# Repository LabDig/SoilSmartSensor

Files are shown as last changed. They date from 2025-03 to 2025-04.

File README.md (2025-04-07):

# SoilSmartSensor

Esse repositório reune a documentação para construção da plataforma multisensor SoilSmartSensor. 

O Soil Smart Sensor é uma plataforma multisensor e portátil em desenvolvimento do Depto de Engenharia Agrícola da Universidade Federal de Viçosa. O Soil Smart Sensor permite medir a condutividade eletríca aparente , o teor de água e a umidade do solo. A operação do multisensor é realizado por aplicativo executado em dispositivo móvel Android.

Projeto Financiado pelo Conselho Nacional de Desenvovlimento Científico e Tecnológico (CNPq). Tìtulo : Desenvolvimento de um sistema inteligente para caracterização da variabilidade espacial do solo em agricultura de precisão . Processo 404374/2021-2 

Equipe de Desenvolvimento e Validação

Andre Luiz de Freitas Coelho

Daniel Marçal de Queiroz

Emanoel Di Tarso dos Santos Sousa

Eduardo Leonel Bottega

Marcelo Marques da Costa

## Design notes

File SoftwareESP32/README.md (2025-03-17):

# SoilSmartSensor

# SoftwareESP32

Esse diretorio contém ao software desenvolvido para a placa de aquisição de dados do Soil Smart Sensor. 

A placa de aquisição do Soil Smart Sensor utiliza como base a placa de desenvolvimento ESP32 S3.

Documentação da placa em https://docs.espressif.com/projects/esp-dev-kits/en/latest/esp32s3/esp32-s3-devkitc-1/index.html

O software foi desenvolvido no Arduino IDE 2.3.2 com firmware para a familia de placas ESP32 versão 3.0.5

Detalhamento dos arquivos e diretórios

/SmartSensor_ESP32  --> contém os arquivos do software desenvolvido para ESP32 S3
 SmartSensor_ESP32.ino  --> arquivo principal com o software
 functions.ino            --> arquivo auxiliar com funções utilizadas.

/NimBLE-Arduino    --> contém a biblioteca para uso do Bluetooth Low Energy

/Sparkfun_ADS1015_Arduino_Library --> contém a biblioteca para uso do módulo ADC ADS1015

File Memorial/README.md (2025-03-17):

# SoilSmartSensor

# Memorial

Esse diretorio contém o Memorial Descrito e Manual de Operação do Soil Smart Sensor. 

Detalhamento dos arquivos e diretórios

Memorial_Manual.pdf --> Memorial Descritivo e Manual de Operação do Soil Smart Sensor

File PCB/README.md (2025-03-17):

# SoilSmartSensor

# PCB

Esse repositório reune a documentação para construção da placa de circuito impresso para o Soil Smart Sensor. 

A placa é desenvolvida com base na ESP32 S3

O projeto do circuito foi desenvolvido utilizando o Fritzing (https://fritzing.org/)

Detalhamento dos arquivos e diretórios

PCB.fpz --> arquivo Fritzing

PCB_Esquematico.pdf --> ciruito eletronico da placa do Soil Smart Sensor

PCB_trilhas.pdf --> trilhas da placa do Soil Smart Sensor

ListaMateriais_PCB.csv --> Lista de materiais para fabricação da PCB e Unidade Eletronica de Controle

/Gerber --> diretorio com os arquivos Gerber para confecção da PCB

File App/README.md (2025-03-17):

# SoilSmartSensor

# App

Esse diretorio contém os arquivos relacionados ao aplicativo Android para operação do Soil Smart Sensor. 

O aplicativo foi desenvolvido utilizando a plataforma online MIT App Inventor (https://appinventor.mit.edu/)

Detalhamento dos arquivos e diretórios

/PrintScreen --> contém capturas de tela do aplicativo

BLE-with-extensios-api.apx --> Extensão para usar os recursos do Bluetooth Low Energy (BLE)

SmartSensor3.aia --> arquivo aia gerado pelo AppInventor. Você pode importar e editar o aplicativo a partir desse arquivo

SmartSensor3.apk --> arquivo APK para instalação do aplicativo em dispositivo Android

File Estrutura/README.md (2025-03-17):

# SoilSmartSensor

# Estrutura

Esse diretorio contém os arquivos relacionados à estrutura (chassi) do Soil Smart Sensor. 

O aplicativo foi desenvolvido utilizando a plataforma online MIT App Inventor (https://appinventor.mit.edu/)

Detalhamento dos arquivos e diretórios

Estrutura.step --> modelagem 3D da estrutura

ListaMateriaisEstrutura.csv --> Lista de materiais e respectivas quantidades para construção da estrutura

DesenhoTecnico.pdf --> Desenho técnico para construção da estrutura

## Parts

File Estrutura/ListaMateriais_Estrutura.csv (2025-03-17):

Qtde | unididade | Descrição
1 | m | TUBO QUADRADO DE ALUMÍNIO 1. 1/2" (38,10 MM) X 1/16" (1,58 MM)
0.25 | m | TUBO REDONDO DE ALUMÍNIO DE 7/8" (22,22 MM) X 1/16" (1,58 MM)
2 | m | PERFIL RETANGULAR AÇO SAE 1020 1.1/2" (38.1 MM) X 3/16" (4.76 MM)
1 | m | BARRA NYLON 6.0 QUADRADO 40 X 40 MM
1 | m | BARRA CIRCULAR INOX AISI 304 1/4" (6.35 MM)
10 | unid. | PARAFUSO SEXTAVADO 1/4" X 2"
10 | unid. | PORCA SEXTAVADA 1/4"
10 | unid. | ARRUELA LISA 1/4"

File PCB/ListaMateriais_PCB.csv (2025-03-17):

Qtde | Unidade | Descrição
1 | unid. | Carregador Portátil PowerBank 5V 10.000 mAh
1 | unid. | PLACA DE DESENVOLVIMENTO ESP32 S3 - ESP32 S3 DEV KIT
6 | unid. | BATERIA 18650 3.7V 3800mAh
2 | unid. | SUPORTE 3 BATERIA 18650
1 | unid. | MÓDULO RELE 5V 2 CANAIS COM OPTOACOPLADOR
2 | unid. | BARRA PINOS FEMEA 1X40 2.54 MM 180 GRAUS
1 | unid. | CONVERSOR ANALOGICO DIGITAL I2C - 10 bits - ADS1015
1 | unid. | MÓDULO MICRO SD SPI 5 V
1 | unid. | BMS 6S 15A 24V
1 | unid. | FONTE 24 V 2 A PLUG P4
1 | unid. | 1 CONECTOR P4
1 | unid. | 1 CABO USB-C
1 | unid. | SENSOR TEMPERATURA PT100 3 FIOS, CABO 2 METROS, SONDA D= 5 MM X L = 100 MM
1 | unid. | CAIXA ABS 200X 100X100 MM
1 | unid. | CHAVE GANGORRA KCD1-202 6 TERMINAIS
1 | unid. | CONECTOR MIKE 6 VIAS
1 | unid. | VOLTIMETRO INFICADOR CARGA BATERIA 18650 6S
1.5 | m | Cabo Flexível 22 AWG (0,30mm) Azul
1.5 | m | Cabo Flexível 22 AWG (0,30mm) Vermelho
1.5 | m | Cabo Flexível 22 AWG (0,30mm) Preto
1.5 | m | Cabo Flexível 22 AWG (0,30mm) Verde
1.5 | m | Cabo Flexível 22 AWG (0,30mm) Amarelo
3 | unid. | Resistor 1.5 kohm 1/4 W
7 | unid. | Resistor 100 kohm 1/4 W
1 | unid. | Resistor 10 kohm 1/4 W
2 | unid. | Resistor 120 ohm 1/4 W
1 | unid. | Resistor 180 ohm 1/4 W
4 | unid. | Resistor 1 kohm 1/4 W
12 | unid. | Resistor 22 kohm 1/4 W
1 | unid. | Resistor 250 ohm 1/4 W
1 | unid. | Resistor 33 kohm 1/4 W
2 | unid. | Resistor 4.7 kohm 1/4 W
1 | unid. | Resistor 5.6 kohm 1/4 W
1 | unid. | Resistor 510 ohm 1/4 W
2 | unid. | Resistor 6.8 kohm 1/4 W
3 | unid. | Resistor 9.1 kohm 1/4 W
2 | unid. | Capacitor Cerâmico 10 nF
1 | unid. | Capacitor Cerâmico 4.7 nF
5 | unid. | Capacitor Eletrolítico 1 uF 16 V
1 | unid. | Amp Op LM741
1 | unid. | Amp Op LM342N
4 | unid. | Amp Op MCP6002
3 | unid. | Amp Op TL072
1 | unid. | Diodo 1N4001
4 | unid. | Conector KRE 2 Vias
1 | unid. | Conector KRE 3 Vias
1 | unid. | Trimport 10 k
1 | unid. | Conversor Step-Down Mini ajustável 5560
6 | unid. | Soquete DIP 8 pinos
1 | unid. | Soquete DIP 14 pinos

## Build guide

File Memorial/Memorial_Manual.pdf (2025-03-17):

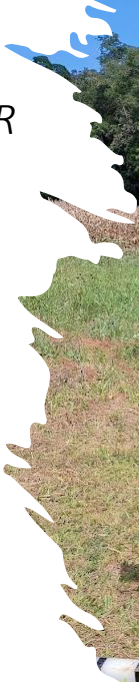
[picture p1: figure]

# PLATAFORMA MULTISENSOR CEA, UMIDADE E TEMPERATURA DO SOLO

# SMART SOIL SENSOR

# MANUAL E MEMORIAL TÉCNICO

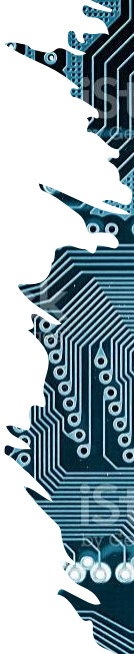
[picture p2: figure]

# PARTE 1 : COMPONENTES

E

# FUNCIONAMENTO

# Plataforma Multisensor

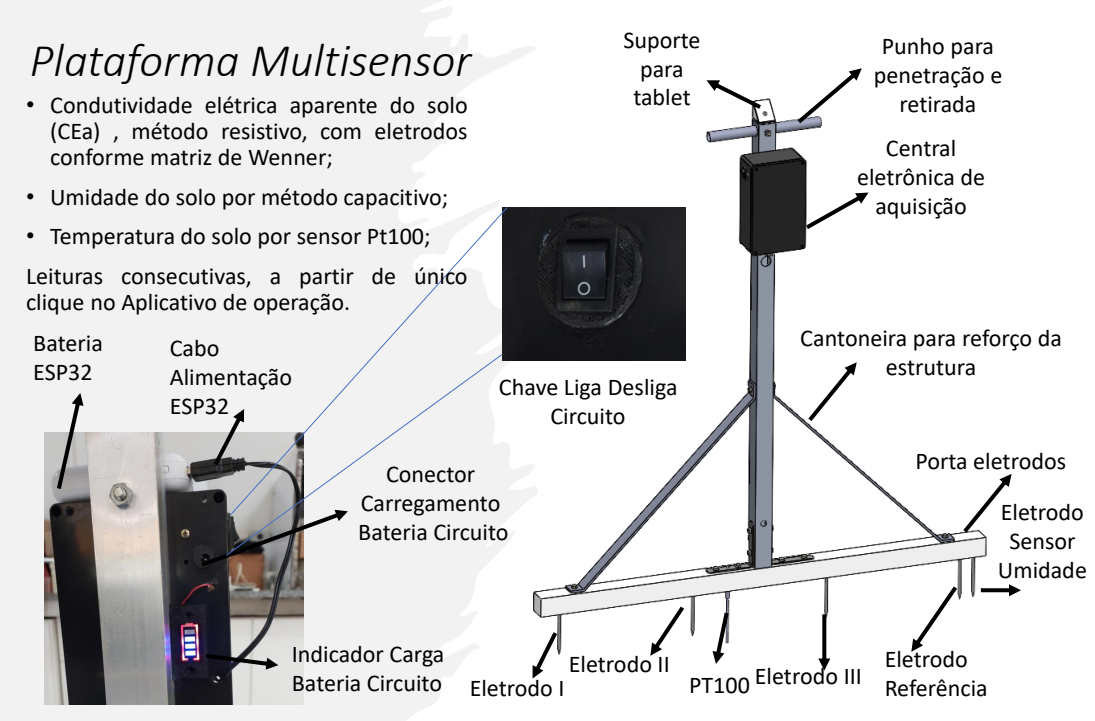
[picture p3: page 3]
Punho para penetração e retirada; Suporte para tablet; Central eletrônica de aquisição; Porta eletrodos; Eletrodo I; Eletrodo Referência; Eletrodo Sensor Umidade; Indicador Carga Bateria Circuito; Conector Carregamento Bateria Circuito; Eletrodo II; Eletrodo III; Cabo Alimentação ESP32; estrutura

• Condutividade elétrica aparente do solo
(CEa) , método resistivo, com eletrodos
conforme matriz de Wenner;
• Umidade do solo por método capacitivo;
• Temperatura do solo por sensor Pt100;
Leituras consecutivas, a partir de único
clique no Aplicativo de operação.
Bateria
ESP32

Cantoneira para reforço da

Chave Liga Desliga
Circuito

# Sensor CEA

- a = 0.3 m;
- h = 9 – 10 cm;

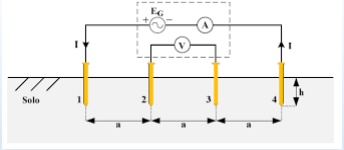
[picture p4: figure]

- EG = Sinal emitido ➔ bipolar , com amplitude – 9 a 9 V, frequência ajustável pelo usuário (3 a 100 Hz) ;
- I = Corrente demandada pelo solo medida a partir da passagem do sinal por resistor com resistência 180 ohm (resistor shunt). Medição da queda de tensão no resistor e cálculo da corrente;
- V = Diferença de potencial nos eletrodos 2 e 3, devido ao sinal elétrico conduzido pelo solo;
- Emissão de sinal ocorre apenas durante leitura da CEa;
- Leitura de 40 pontos dos sinais com taxa de amostragem 8x frequência sinal:
- Queda de tensão no R180 ➔ cálculo CEa e algoritmo de contato;
- Diferença de tensão E2 – Referência ➔ cálculo CEa e algoritmo de contato;
- Diferença de tensão E3 – Referência ➔ cálculo CEa e algoritmo de contato ;
- Cálculo de sinal referente à diferença de potencial entre eletrodo 2 e 3 ➔ cálculo CEa e algoritmo de contato ;
- Cálculo do absoluto dos valores de tensão (queda de tensão R180) e diferença de potencial dos eletrodos intermediários) ➔ cálculo da tensão média do absoluto ➔ cálculo de CEa;

CEa (

mS
m

) =

i (mA)
2 ∙ π ∙ a m ∙ V (V)

!!!!Absoluto : transforma parte negativa do sinal bipolar em positivo por função matemática abs().

# Sensor Umidade Solo

Geração de sinal
contínuo (3V?)

Eletrodo Sensor Umidade

Filtro Resistivo-Capacitivo Condicionamento do sinal (divisor de tensão e filtro)

- Princípio capacitivo : solo atua como capacitor em um filtro RC;
- Solo Seco ➔ Menor Capacitância ➔ Maior tensão SIG_m;
- Solo Úmido ➔ Maior Capacitância ➔ Menor tensão SIG_m;
- Calibração para obter a umidade (gravimétrica ou volumétrica) a partir da tensão SIG_m.

Eletrodo Referência

# Sensor Temperatura Solo

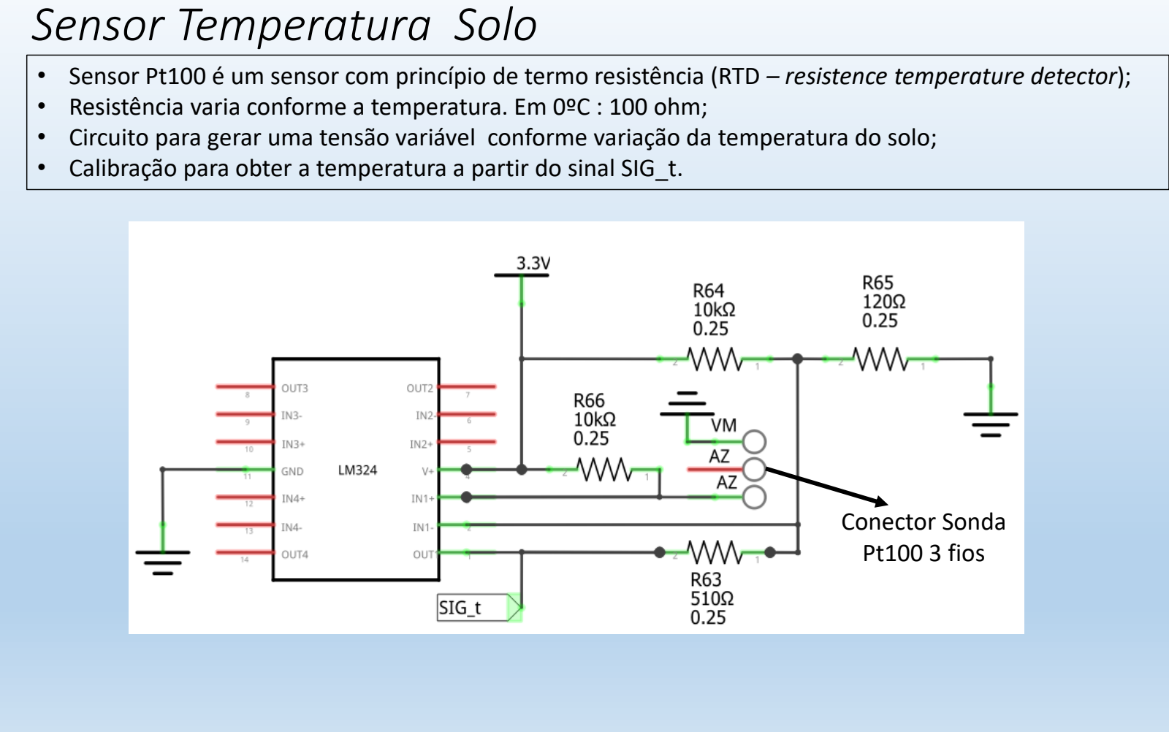
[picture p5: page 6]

- Sensor Pt100 é um sensor com princípio de termo resistência (RTD – resistence temperature detector);
- Resistência varia conforme a temperatura. Em 0ºC : 100 ohm;
- Circuito para gerar uma tensão variável conforme variação da temperatura do solo;
- Calibração para obter a temperatura a partir do sinal SIG_t.

Conector Sonda
Pt100 3 fios

# Central eletrônica de aquisição

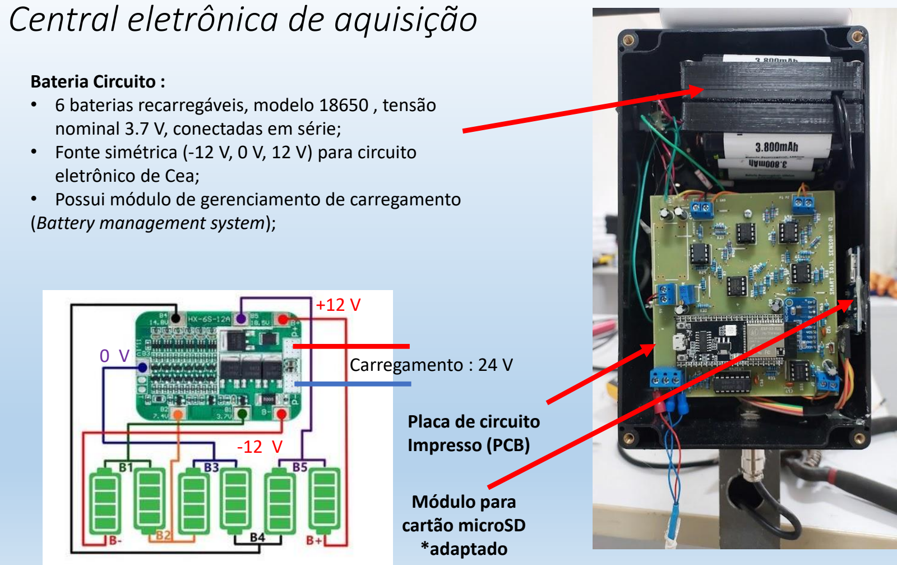
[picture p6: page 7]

Bateria Circuito :
- 6 baterias recarregáveis, modelo 18650 , tensão nominal 3.7 V, conectadas em série;
- Fonte simétrica (-12 V, 0 V, 12 V) para circuito eletrônico de Cea;
- Possui módulo de gerenciamento de carregamento (Battery management system);

Carregamento : 24 V

+12 V

0 V

-12 V

Placa de circuito
Impresso (PCB)

Módulo para
cartão microSD
*adaptado

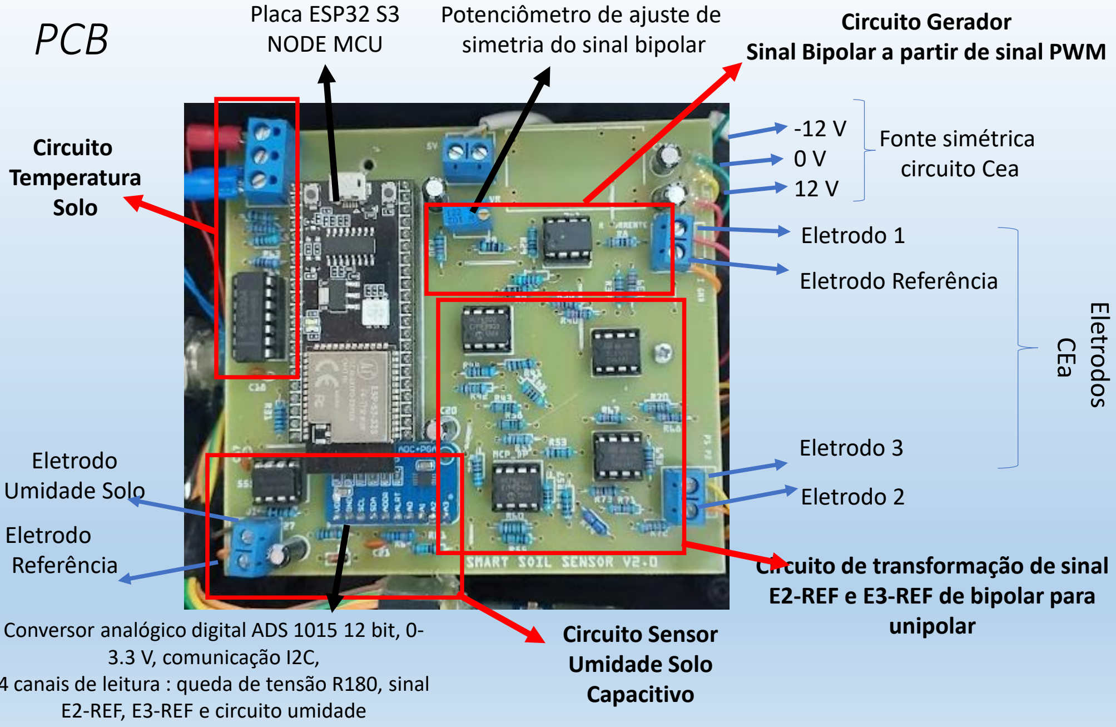
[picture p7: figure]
Placa ESP32 S3 NODE MCU; Eletrodo 1; Eletrodo Referência; Eletrodo 3; Eletrodo 2; Potenciômetro de ajuste de simetria do sinal bipolar; Fonte simétrica circuito Cea; Eletrodos; CEa; Eletrodo Umidade Solo; 3.3 V, comunicação I2C,; E2-REF, E3-REF e circuito umidade; Circuito Sensor Umidade Solo Capacitivo; Circuito Gerador Sinal Bipolar a partir de sinal PWM; Circuito de transformação de sinal E2-REF e E3-REF de bipolar para unipolar; PCB; Circuito Temperatura Solo

Conversor analógico digital ADS 1015 12 bit, 0-

4 canais de leitura : queda de tensão R180, sinal

# PCB

Placa ESP32 S3

-12 V
0 V
12 V

Eletrodo 1

Eletrodo Referência

Eletrodo 3

Eletrodo 2

Potenciômetro de ajuste de simetria do sinal bipolar

Fonte simétrica
circuito Cea

Eletrodos

CEa

Eletrodo
Referência

Eletrodo
Umidade Solo

Conversor analógico digital ADS 1015 12 bit, 0-3.3 V, comunicação I2C,
4 canais de leitura : queda de tensão R180, sinal E2-REF, E3-REF e circuito umidade

Circuito Sensor
Umidade Solo
Capacitivo

Circuito Gerador
Sinal Bipolar a partir de sinal PWM

Circuito de transformação de sinal E2-REF e E3-REF de bipolar para unipolar

Circuito
Temperatura
Solo

Acionamento
Relés

Alimentação 5V

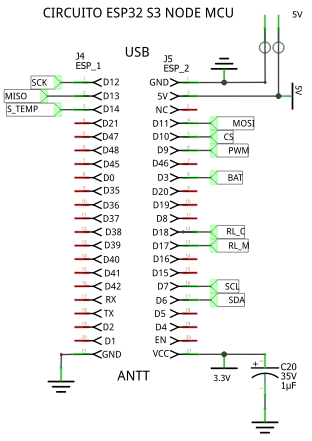
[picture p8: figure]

5V : Entrada de energia para alimentar ESP32-S3

GND : Referência (0V)

3.3V : fornecimento de 3.3V para Circuitos diversos

PWM : sinal PWM para Gerador de Sinal Bipolar

BAT : medição da tensão da bateria do circuito (+12V)

RL_C : acionamento do relé de emissão do sinal para medição da Cea

RL_M : acionamento do relé do sinal para medição da umidade

SCL e SDA : comunicação I2C com ADS1015

S_TEMP : sinal do sensor de temperatura

SCK, MISO, MOSI, CS : comunicação SPI com módulo microSD

# Circuito ESP32-S3 NODE MCU

# Circuito Tensão Baterias 18650 , ADS1015 e Relés

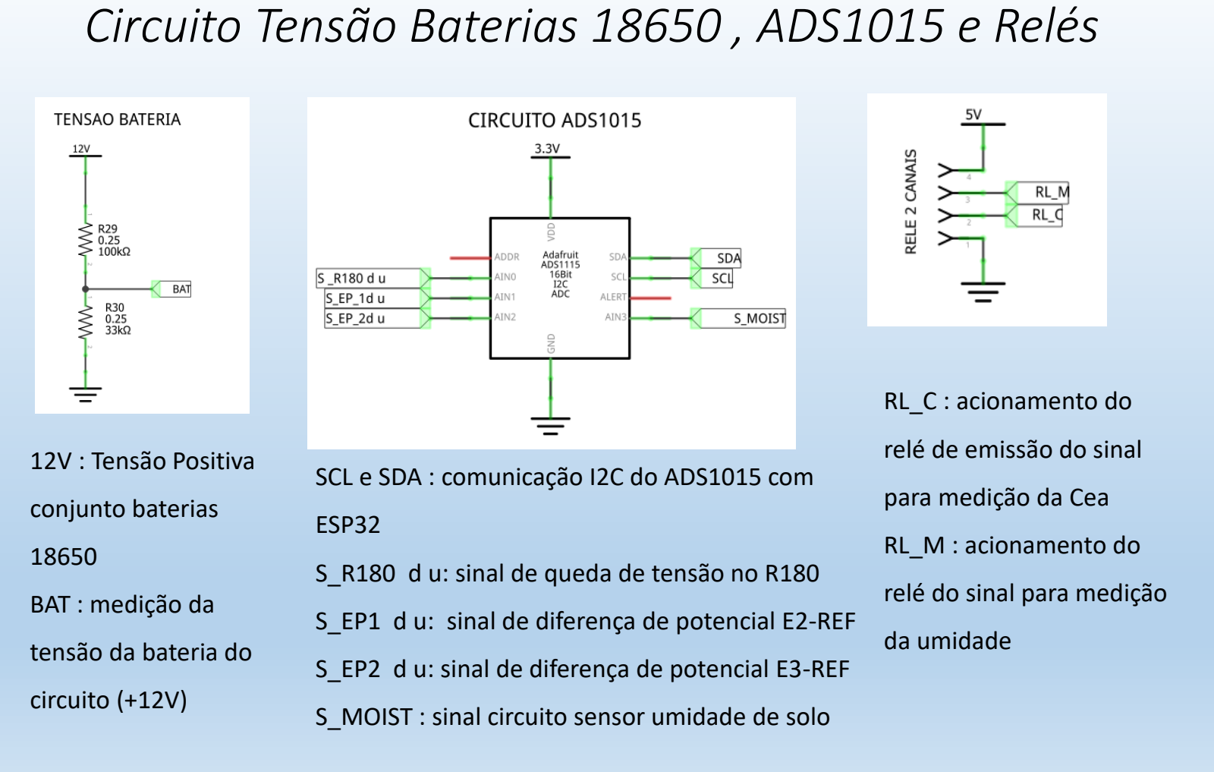
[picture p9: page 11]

12V : Tensão Positiva

conjunto baterias

18650

BAT : medição da

tensão da bateria do

circuito (+12V)

SCL e SDA : comunicação I2C do ADS1015 com

ESP32

S_R180 d u: sinal de queda de tensão no R180

S_EP1 d u: sinal de diferença de potencial E2-REF

S_EP2 d u: sinal de diferença de potencial E3-REF

S_MOIST : sinal circuito sensor umidade de solo

RL_C : acionamento do

relé de emissão do sinal

para medição da Cea

RL_M : acionamento do

relé do sinal para medição

da umidade

5V : Alimentação

GND : Referência (0V)

MOSI : Master Out Slave In

MISO : Master In Slave Out

SCK : Serial Clock

CS : Chipt Select

# Circuito Módulo MicroSD

SPI

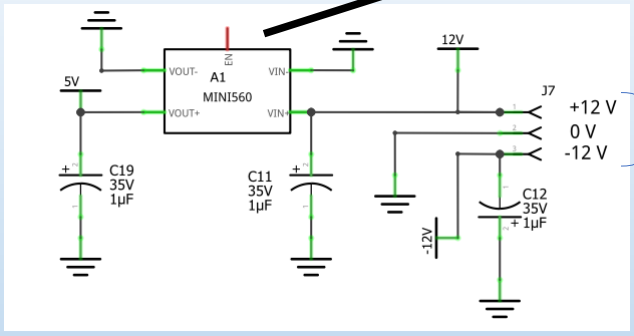
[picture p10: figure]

12V : Tensão Positiva conjunto baterias 18650

-12V : Tensão Negativa conjunto baterias 18650

5 V : Tensão para alimentar ESP32 S3 e Gerador Bipolar

! Não está sendo usado na versão atual do Smart Soil Sensor

# Circuito Regulador de Tensão

Conversor de tensão Mini 560 DC-DC 12 V ➔ 5V

Fonte simétrica
circuito

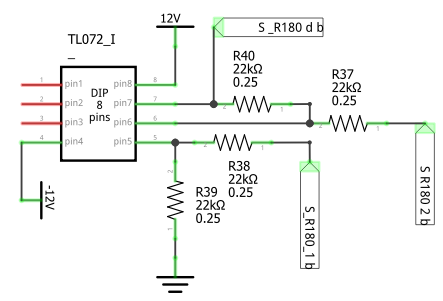
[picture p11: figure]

S_R180 d b : sinal da queda de tensão no R180 (sinal bipolar)

# Circuito Gerador de sinal diferencial para queda de tensão R180

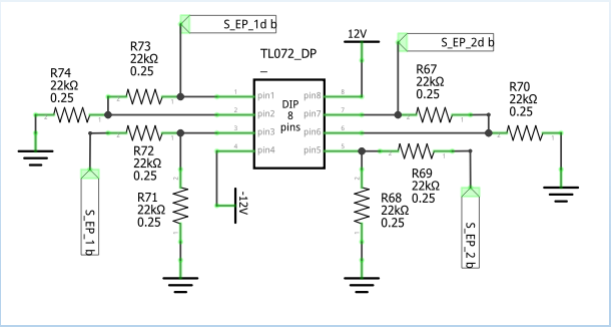
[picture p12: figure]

S_EP_1 d b : sinal potencial eletrodo E2 em relação ao GND (sinal bipolar)

S_EP_2 d b : sinal potencial eletrodo E3 em relação ao GND (sinal bipolar)

# Circuito Gerador de sinal diferencial Eletrodos E2 e E3

# Diagrama Transformador de sinal bipolar (-5 a 5 V ) em sinal unipolar (0 a 3.3V) Queda Tensão R180

S_R180 d b : queda de tensão no R180 bipolar➔ S_R180 d u : queda de tensão no R180 unipolar

# Diagrama Transformador de sinal bipolar (-5 a 5 V ) em sinal unipolar (0 a 3.3V)

Desenvolvido com base no circuito apresentado em Molloy, D. Exploring BeagleBone : Tools and Techniques for Building With Embeeded Linux. Indianapolis : John Willey& Sons, Inc. 20215.

Circuito com base no amplificador operacional MCP6002

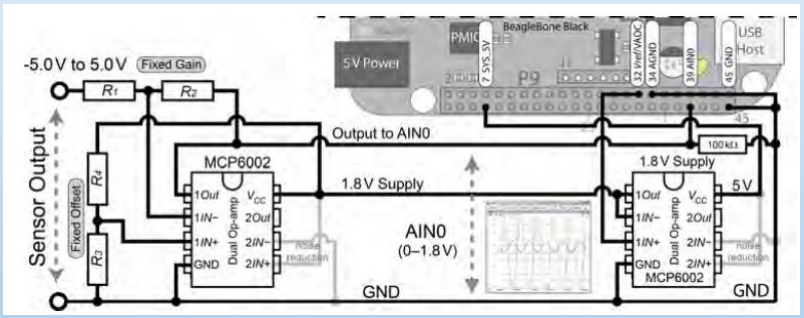
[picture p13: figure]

Equação matemática do circuito

# Circuito Transformador de sinal bipolar (-5 a 5 V ) em sinal unipolar (0 a 3.3V) Eletrodos E2 e E3

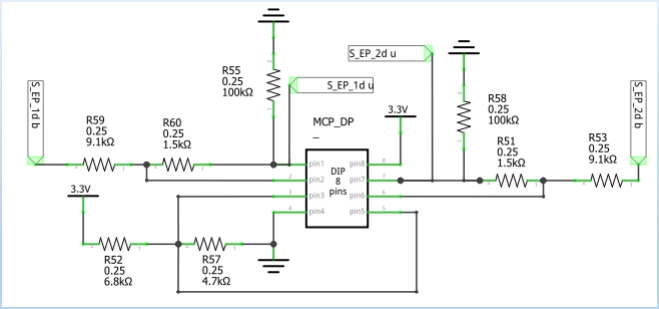
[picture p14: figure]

S_EP1 d b : diferença potencial E2-REP bipolar➔ S_EP1 d u : diferença potencial E2-REP unipolar

S_EP2 d b : diferença potencial E3-REP bipolar➔ S_EP2 d u : diferença potencial E3-REP unipolar

# Circuito sensor de umidade do solo

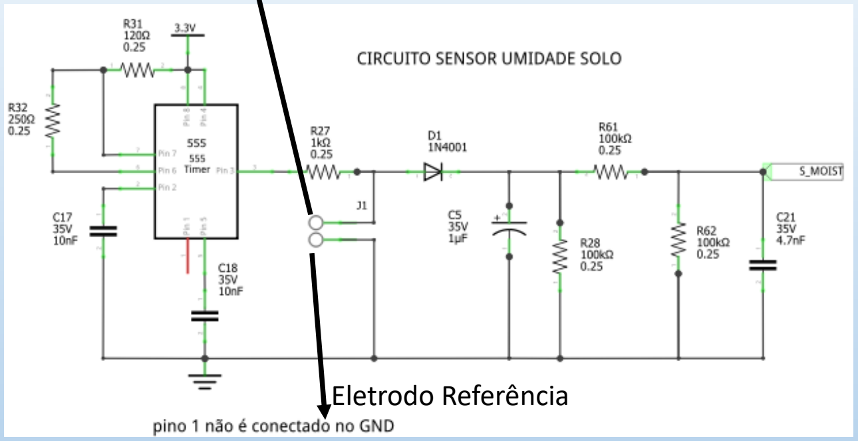
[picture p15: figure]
Eletrodo Referência

Sinal SIG_MOIST está relacionado com a umidade do solo ➔ Leitura no canal 3 do ADS1015

Umidade baixa ➔ maior tensão / umidade alta ➔ menor tensão

Requer calibração experimental para gerar equação matemática para determinar umidade

Eletrodo Sensor Umidade

* Sinal enviado para Eletrodo Sensor Umidade é interrompido por relé , quando o sensor não está medindo umidade do solo

# Circuito sensor de temperatura do solo

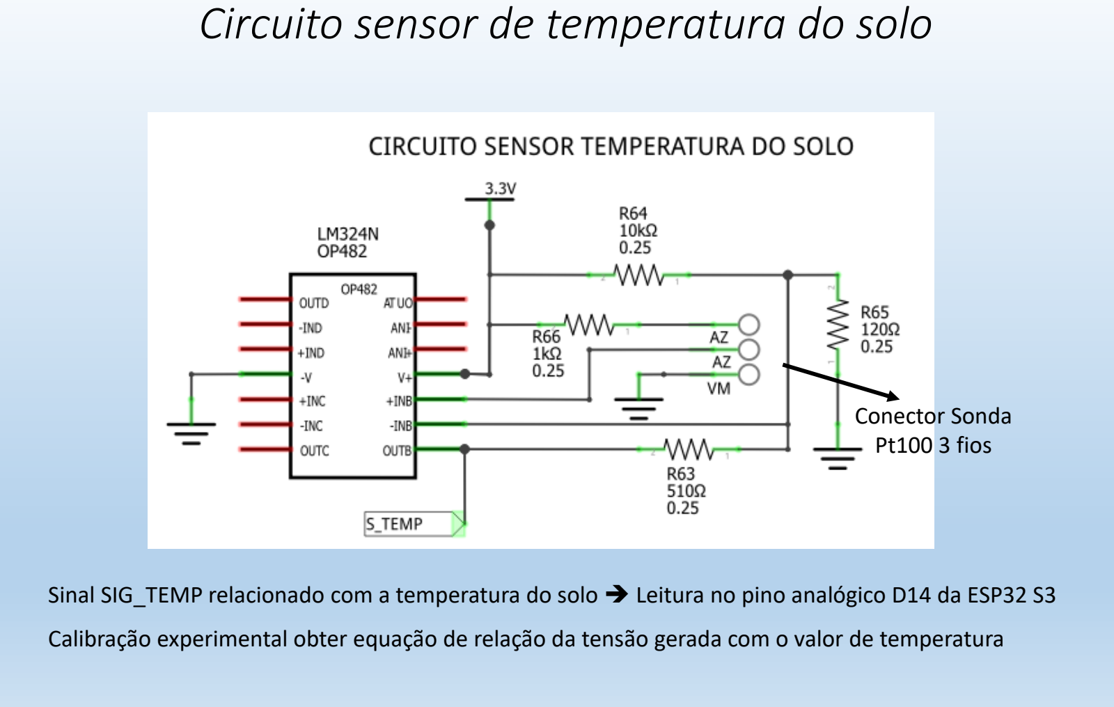
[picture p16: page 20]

Sinal SIG_TEMP relacionado com a temperatura do solo ➔ Leitura no pino analógico D14 da ESP32 S3

Calibração experimental obter equação de relação da tensão gerada com o valor de temperatura

Conector Sonda
Pt100 3 fios

# PARTE 2 : PROGRAMA

DE

# COMPUTADOR

# Fluxograma Programa

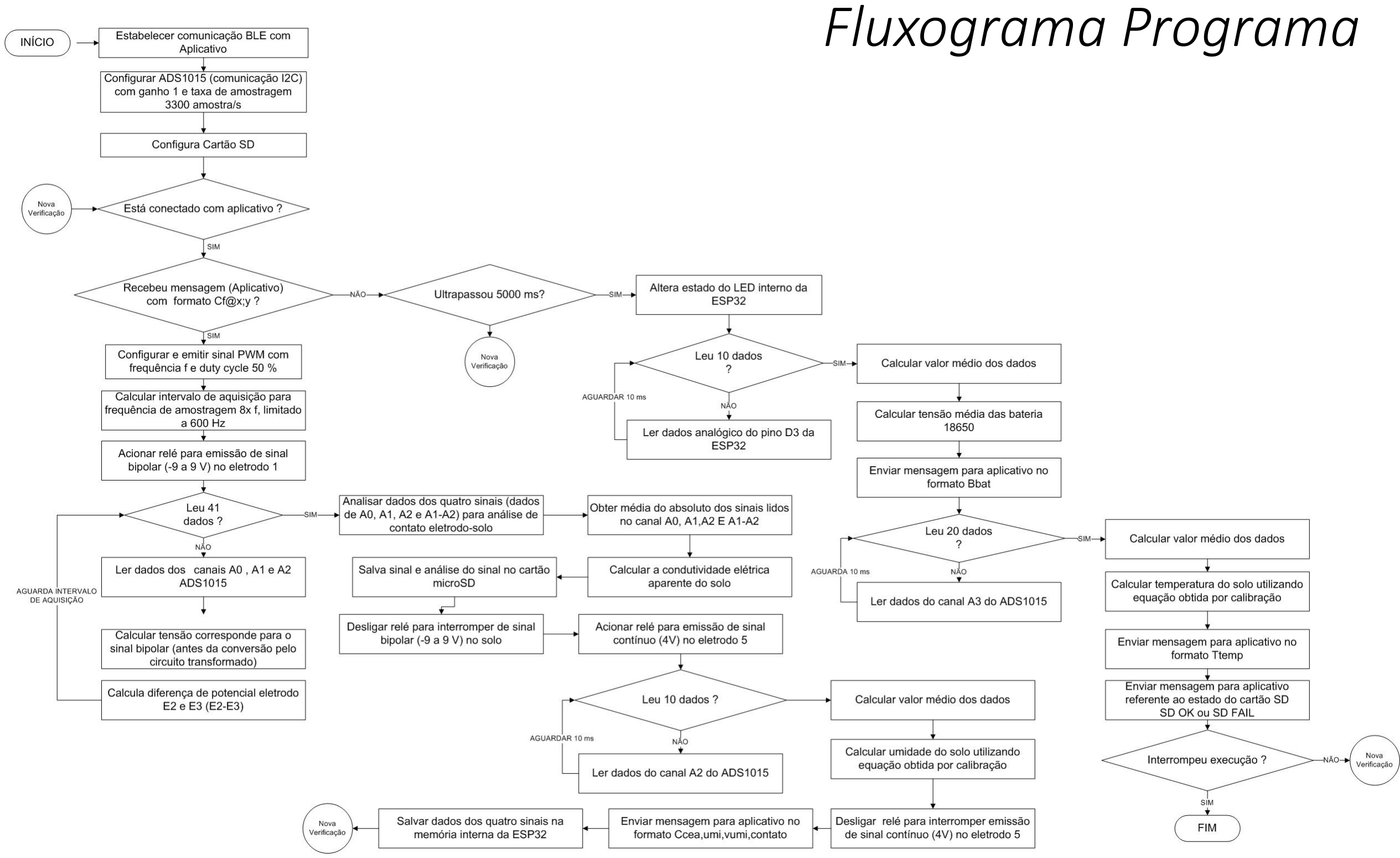
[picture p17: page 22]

# Detalhes do cálculo da CEa

- Para o sinal de queda de tensão no R180 :
- Calcula o valor médio do sinal absoluto ➔ tensões negativas são convertidas em

positivas;

- Calcula a corrente média do sinal;
- Para o sinal de diferença de potência entre eletrodos E2 e E3:
- Calcula o valor médio do sinal absoluto ➔ tensões negativas são convertidas em

positivas;

- Calcula a Cea, usando a equação: CEa (

mS
m

) =

i (mA)
2 ∙ π ∙ a m ∙ V (V)

# Detalhes do algoritmo de contato

- Após a aquisição dos 40 dados dos 4 sinais (R180, E2-REF, E3-REF, E2-E3), eles são analisados.
- Durante a análise, cada um dos 4 sinais é divido em alto (HIGH) e baixa (LOW):
- Após a contagem do número de dados em HIGH e LOW , é calculado a razão entre

número de dados entre LOW e HIGH (rn_lh);

- Após o cálculo da tensão média em HIGH e LOW , É calculado a razão entre a tensão em

HIGH e LOW (rv_lh);

# Detalhes do algoritmo de contato

- Hipóteses adotadas para o desenvolvimento do algoritmo:
- 1 ) O sinal emitido no solo é bipolar e simétrico. Então, o número de pontos na parte HIGH

e LOW de cada um dos quatro sinais precisam ser próximos (razão rn_lh próximo de 1).

- 2 ) O sinal emitido Sinal emitido é bipolar e simétrico. Então, a magnitude da tensão média

em HIGH e LOW dos sinais usados para calcular Cea ser próximos (rv_lh próximo de -1).

- Caso algum critério, em algum sinal, não seja atendido, o algoritmo acusa mal contato eletrodo-

solo (contato=N)

- Caso todos os critérios sejam atendidos, o algoritmo considerado contato perfeito (contato = S)

# Detalhes do algoritmo de contato

Faixa de valores para os critérios, definidos após testes em laboratório e campo :

- A razão rn_lh dos sinais precisa estar em 0.5 e 1.5
- A razão rv_lh dos sinais precisa estar em -0.25 e -1.75 *
- Para os quatro sinais R180 (i), E2-REF(EP1), E3-REF(EP2) e E2-E3 (DP), os valores de nl,nh,rn_lh,vl,vh,rv_lh e média (mean) são salvos no arquivo analise.txt
- Os sinais são salvos no arquivo signal.txt
- O programa Python analisa_sinal.py permite analisar o arquivo signal.txt , gerando gráficos do sinal e arquivo com as métricas relacionadas ao sinal.
- O programa Python analisa_dataset.py permite mesclar o arquivo dataset.txt com o arquivo contendo tais métricas.

# Cenário de contato perfeito (solo)

Sinal diferença tensão
Eletrodo E2-REF Sinal queda

tensão R180

Sinal diferença tensão
Eletrodo E2-E3

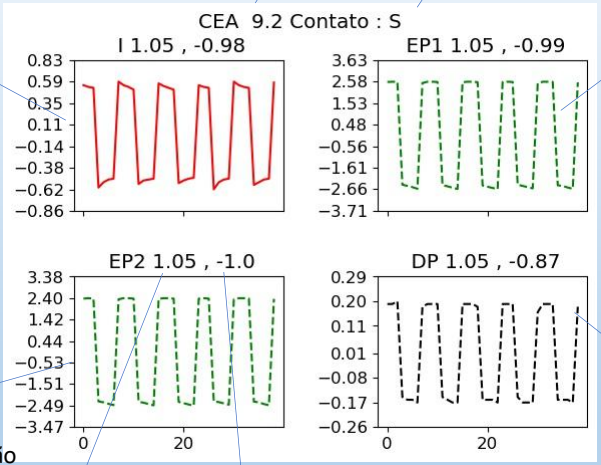
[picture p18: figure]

Sinal diferença tensão
Eletrodo E3-REF

CEA (mS/m)
Contato ?

-0.25 < RV_LH<-1.75 ?

0.5 < RN_LH<1.5 ?

Gráfico gerados em
programa Python
(analise_sinal.py),
usando os dados
gravados no cartão
microSD

# Cenário de contato imperfeito

Sinal diferença tensão
Eletrodo E2-REF Sinal queda

tensão R180

Sinal diferença tensão
Eletrodo E2-E3

Sinal diferença tensão
Eletrodo E3-REF

CEA (mS/m)
Contato ?

-0.25 < RV_LH<-1.75 ?

0.5 < RN_LH<1.5 ?

Gráfico gerados em
programa Python
(analise_sinal.py),
usando os dados
gravados no cartão
microSD

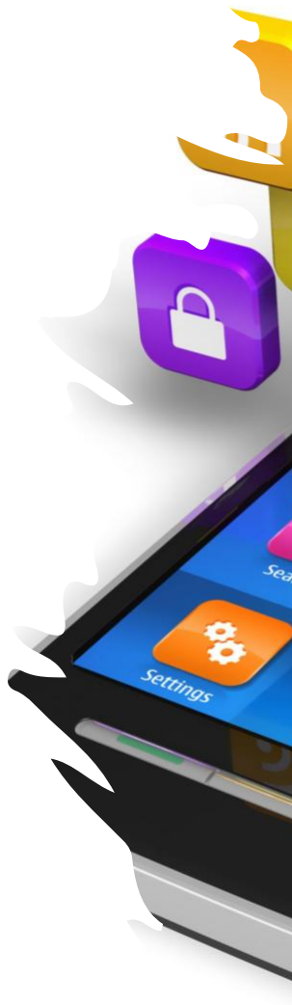
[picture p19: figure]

# PARTE 3 : APLICATIVO

DE

# OPERAÇÃO SMART SENSOR

Descrição dos campos | NOME ARQUIVO : gera , automaticamente, nome do arquivo que será salvo em Documentos/SmartSensor. A pasta e arquivo são gerados, automaticamente , pelo Aplicativo, mesmo que deletados. O formato do arquivo é dataset-yy-mm-dd.txt. A cada dia de coleta, um novo arquivo é gerado.
| ID PROXIMO PONTO : Apresenta o ID do próximo ponto. O ID tem formato X.Y. Onde X é o ID do ponto de fato, e Y é a repetição para aquele ponto. X e Y podem ser editado clicando sobre os respectivos campos. O ID é reiniciado para 1.2 sempre que um novo arquivo é criado. O valor é mantido pelo Aplicativo, mesmo que seja fechado.
| FREQUÊNCIA : Mostra a frequência do sina usando para medição da CEa. O valor pode ser editado clicando sobre o campo. O último valor editado é mantido pelo Aplicativo, mesmo que ele seja fechado.

Descrição dos campos | DATA E HORA : Data e Hora atual obtido do sistema Android. ULTIMO ID : id do último ponto salvo, formato X;Y LAT e LONG : Latitude e Longitude, datum WGS84, em formato de graus e decimal, obtido pelo sensor GNSS do Tablet PRECISÃO : precisão da localização indicada pelo Tablet ALTITUDE : altitude, em relação ao nível do mar, calculada pelo sensor GNSS do tablet CEa SOLO : CEA do solo na última medição. TEMP. SOLO : valor de temperatura do solo na última medição. UMIDADE . SOLO : umidade gravimétrica do solo na última medição, seguido da tensão medida pelo circuito. BATERIA SENSOR : tensão da bateria do sensor. !Interromper a coleta se ficar vermelho
| CONTATO ELETRODO SOLO : S indica contato e N
| indica ausência de contato
SD OK : salvando sinais e analise no cartão microSD SD FAIL : falha no salvamento.

# Descrição dos botões

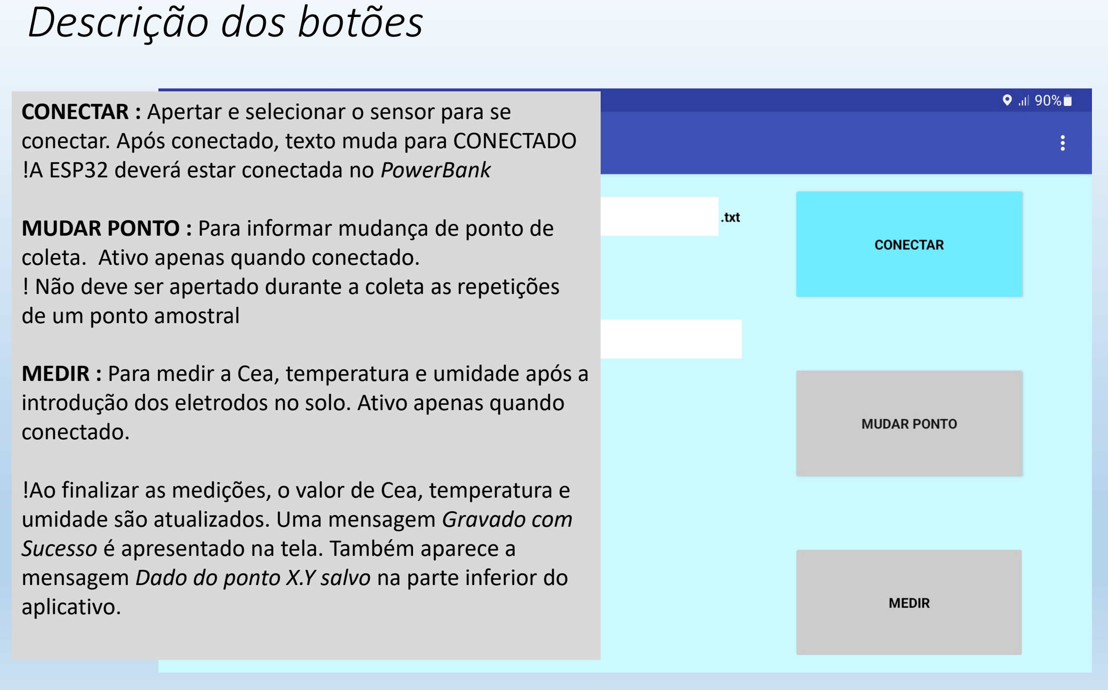
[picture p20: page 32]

CONECTAR : Apertar e selecionar o sensor para se conectar. Após conectado, texto muda para CONECTADO !A ESP32 deverá estar conectada no PowerBank

MUDAR PONTO : Para informar mudança de ponto de coleta. Ativo apenas quando conectado.
! Não deve ser apertado durante a coleta as repetições de um ponto amostral

MEDIR : Para medir a Cea, temperatura e umidade após a introdução dos eletrodos no solo. Ativo apenas quando conectado.

!Ao finalizar as medições, o valor de Cea, temperatura e umidade são atualizados. Uma mensagem Gravado com Sucesso é apresentado na tela. Também aparece a mensagem Dado do ponto X.Y salvo na parte inferior do aplicativo.

# Descrição dos botões

Quando o botão CONECTAR é apertado, surge uma lista de dispositivos próximos para ser selecionado.

Após conectado:
- Botão CONECTAR muda para CONECTADO
- Botão MUDAR PONTO ativo
- Botão MEDIR ativo

Para fechar aplicativo :
- Clicar nos três pontos (1) e em Stop this application (2)

2

1

# Descarregamento dos dados do Tablet

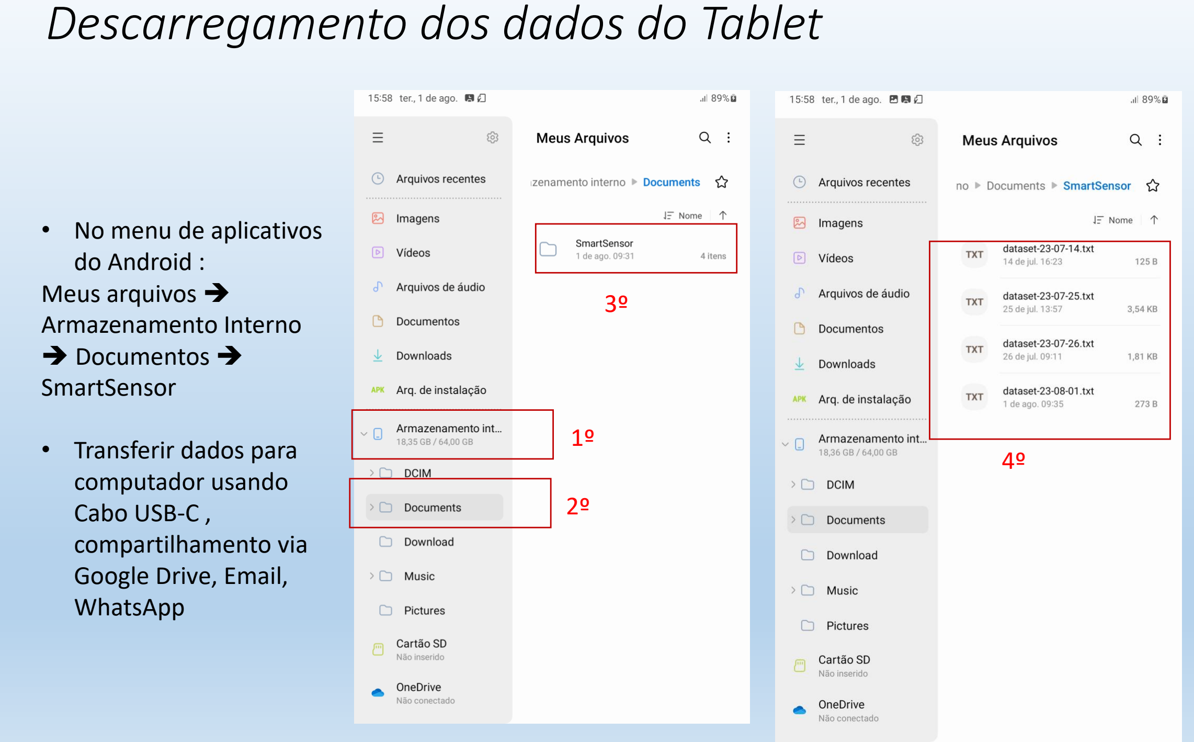
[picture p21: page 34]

- No menu de aplicativos
do Android :
Meus arquivos ➔
Armazenamento Interno
➔ Documentos ➔
SmartSensor
- Transferir dados para
computador usando
Cabo USB-C ,
compartilhamento via
Google Drive, Email,
WhatsApp

1º

2º

3º

4º

# Visualização dos dados do Tablet

Dados em formato csv , utilizando ponto-e-vírgula (;) como separador

Data/hora : data e hora de coleta do dado Id : identificação do ponto
Rep : identificação da repetição para o ponto
Bat : tensão bateria circuito
Lat e Long : latitude e longitude do ponto de coleta Alt : altitude do ponto de coleta

Freq : frequência do sinal emitido no solo, em Hz CEA : condutividade elétrica aparente, em mS/m Temp : temperatura, em ºC
Umi : umidade gravimétrica, em %
Vumi : tensão corresponde à umidade, em V Contact : contato com solo

# Descarregamento dos dados cartão SD

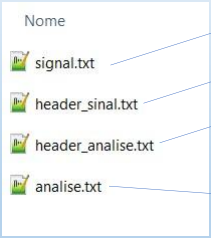
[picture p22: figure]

Arquivo com os dados dos sinais obtidos em cada amostra

Cabeçalho do arquivo de sinais

Cabeçalho do arquivo de analise dos sinais

Arquivo com a análise dos sinais pela ESP32 durante o cálculo da CEA e detecção de contato

Arquivo signal.txt | O sensor não insere cabeçalho no arquivo

! O id;rep é reiniciado
em 1;1 a cada dia
coleta

Arquivo analise.txt | O sensor não insere cabeçalho no arquivo

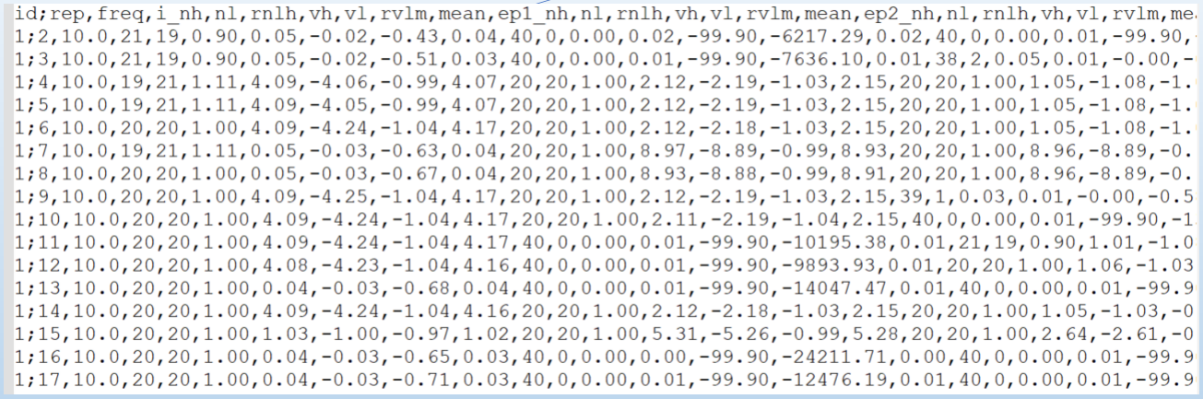
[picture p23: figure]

# Análise dos dados

Programa analise_dataset.py , lê arquivo dataset-YY-mm-dd.txt

- Para os pontos com mesmo Id (pontos da repetição para um dado ponto amostral), calcula-se
- Primeiro valor de data/hora ;
- Último valor de tensão de bateria para o ponto com Id i;
- Valor médio de latitude e longitude ;
- Valor médio de altitude;
- Valor médio e mediano de Cea, considerando e descartando dados sem contato (N)
- Valor médio de umidade;
- Valor médio de temperatura

Novo banco de dados é gerado e salvo com nome proc_dataset-YY-mm-dd.csv.

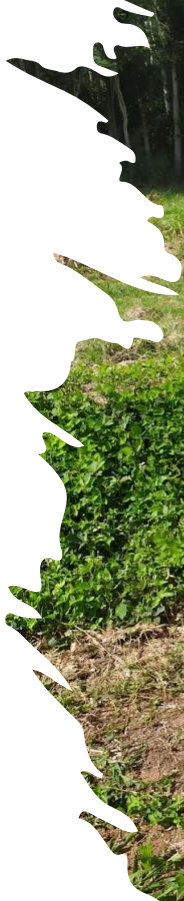
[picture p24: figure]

# PARTE 4 : ORIENTAÇÕES PARA OPERAÇÃO

- Verificar Tensão Bateria Tablet (mínimo de 30 %)
- Verificar Tensão Bateria Power Bank (mínimo de 30 %)
- Verificar Tensão Bateria Circuito (3 ou 4 barras)
- Carregar , usando os respectivos carregadores, se necessário
- Verificar se cartão SD está instalado no módulo
- Verificar a existência de cabos rompidos
- Verificar o aperto dos parafusos da estrutura
- Verificar o aperto dos eletrodos
- Durante o transporte , evitar queda e impactos no sensor

# Antes da Ida para Campo

- Verificar a existência de cabos rompidos
- Ligar o tablet e abrir o aplicativo. Aguardar a conexão com o sistema GPS
- Ligar a chave geral do circuito
- Conectar o cabo de alimentação da ESP32 no PowerBank
- Estabelecer comunicação entre a Unidade Eletrônica de Aquisição e o Tablet
- Conectar os cabos de resistores para teste nas hastes do sensor.
- Editar ID ponto para ZERO (para facilitar o descarte durante processamento). Clicar no botão MEDIR

e aguardar a leitura. Os valores precisam ser próximos à :

# Antes da Coleta

Cor | Resistência | Cea (mS/m) | Tensão Umidade (V)
Preto | 470 | 1,1 | 0,7
Vermelho | 47 | 11,3 | 0,7
Verde | 8,2 | 64,7 | 0,7

- Escolher o local de medição:
- Evitar locais com pedras, raízes e objetos estranhos
- Evitar solo extremamente compactado
- Evitar solo recém mobilizado
- Evitar locais com irregularidade
- Introduzir os eletrodos no solo. Recomenda-se pisar sobre a haste porta eletrodo para melhor introdução em solos compactados.
- Clicar no botão MEDIR e aguardar a leitura. Caso o algoritmo detecte mal contato entre alguma das hastes e o solo, o valor de Contato será N. Caso detecte contato o valor de Contato será S.
- Recomenda-se observar o comportamento do valores e interromper a coleta , para verificar o funcionamento do sensor, em caso de apresentação de valores anormais.
- Interromper a coleta em caso de bateria fraca no tablet, PowerBank ou circuito.
- Sempre verificar integridade dos cabos e das hastes;
- Realizar limpeza dos eletrodos hastes de nova medição.

# Durante a coleta

- Descarregar os dados do Tablet e desligá-lo.
- Descarregar os dados do cartão de memória SD.
- Carregar se necessário
- Desconectar o cabo de alimentação da ESP32. Carregar o Power bank , se necessário
- Desligar a chave geral do circuito. Carregar , se necessário
- Guardar o equipamento limpo.

# Após a coleta

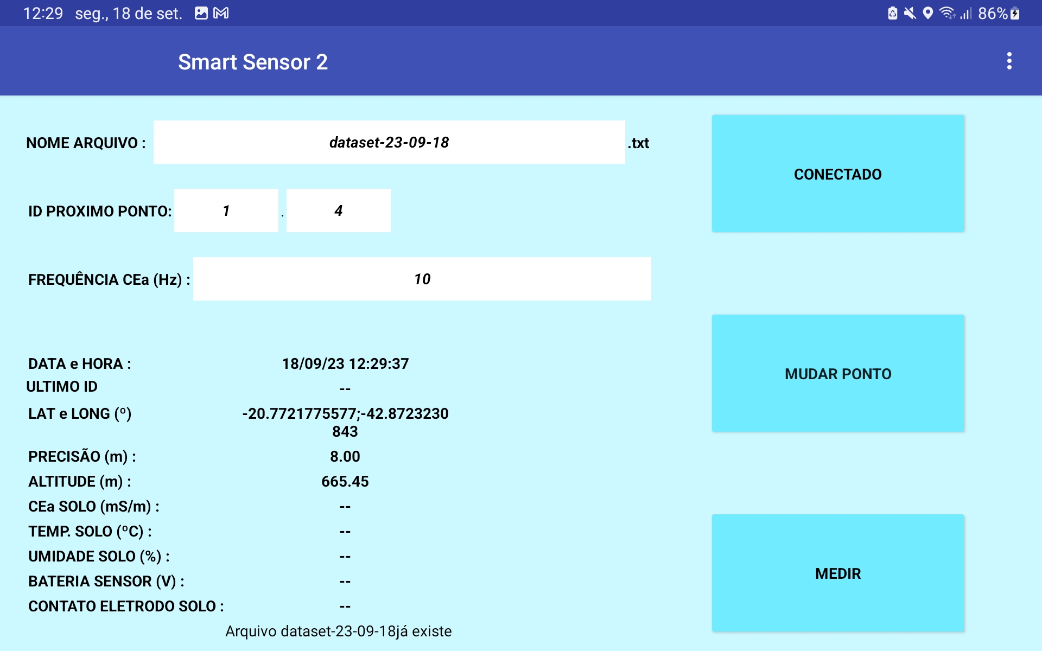
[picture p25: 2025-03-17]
App/PrintScrenn/Screenshot_20230918_122938.jpg

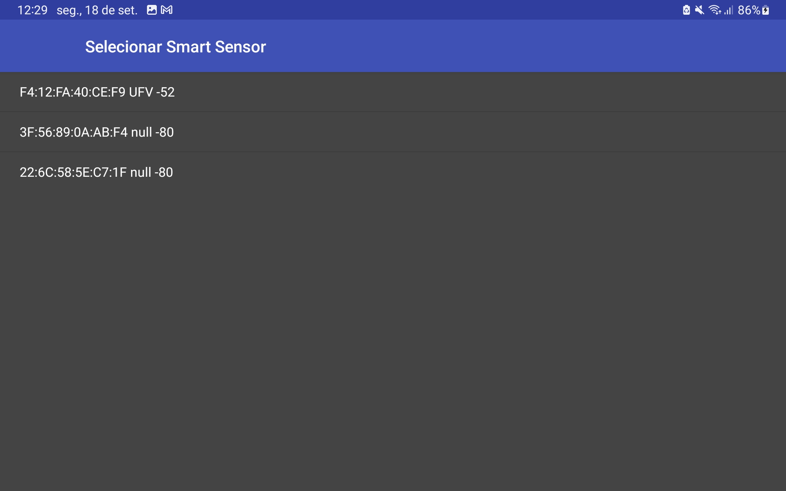
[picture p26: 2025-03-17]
App/PrintScrenn/Screenshot_20230918_122933.jpg

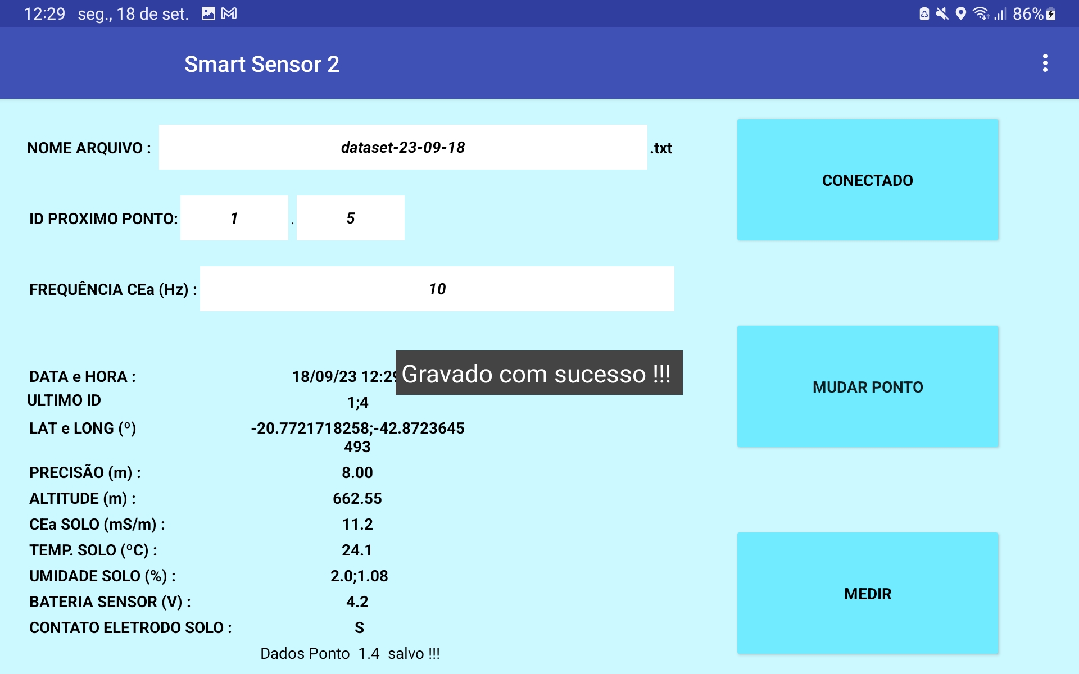
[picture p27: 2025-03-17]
App/PrintScrenn/Screenshot_20230918_122950.jpg

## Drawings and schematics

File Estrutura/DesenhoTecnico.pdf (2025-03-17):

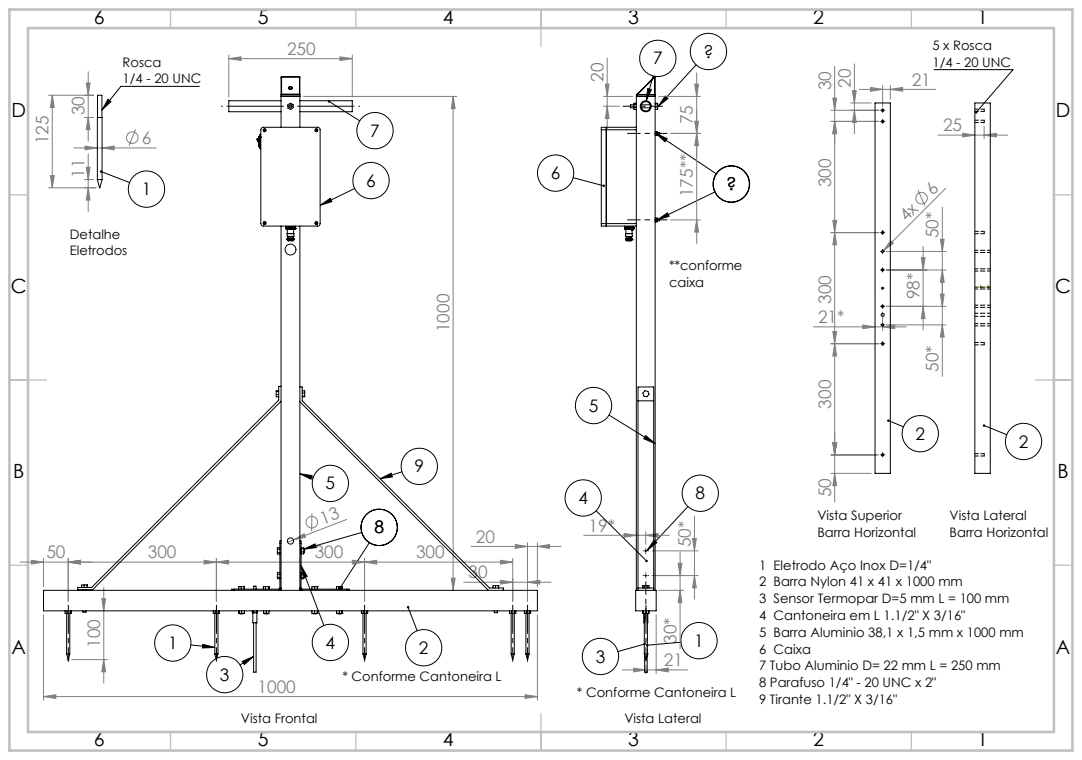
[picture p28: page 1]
* Conforme Cantoneira L; * Conforme Cantoneira L 75 175** 20; 5 x Rosca 1/4 - 20 UNC; 1/4 - 20 UNC; Vista Frontal; Vista Lateral; Vista Superior Barra Horizontal; Vista Lateral Barra Horizontal

1 Eletrodo Aço Inox D=1/4"
2 Barra Nylon 41 x 41 x 1000 mm
3 Sensor Termopar D=5 mm L = 100 mm
4 Cantoneira em L 1.1/2" X 3/16"
5 Barra Aluminio 38,1 x 1,5 mm x 1000 mm

6 Caixa
7 Tubo Aluminio D= 22 mm L = 250 mm
8 Parafuso 1/4" - 20 UNC x 2"
9 Tirante 1.1/2" X 3/16"

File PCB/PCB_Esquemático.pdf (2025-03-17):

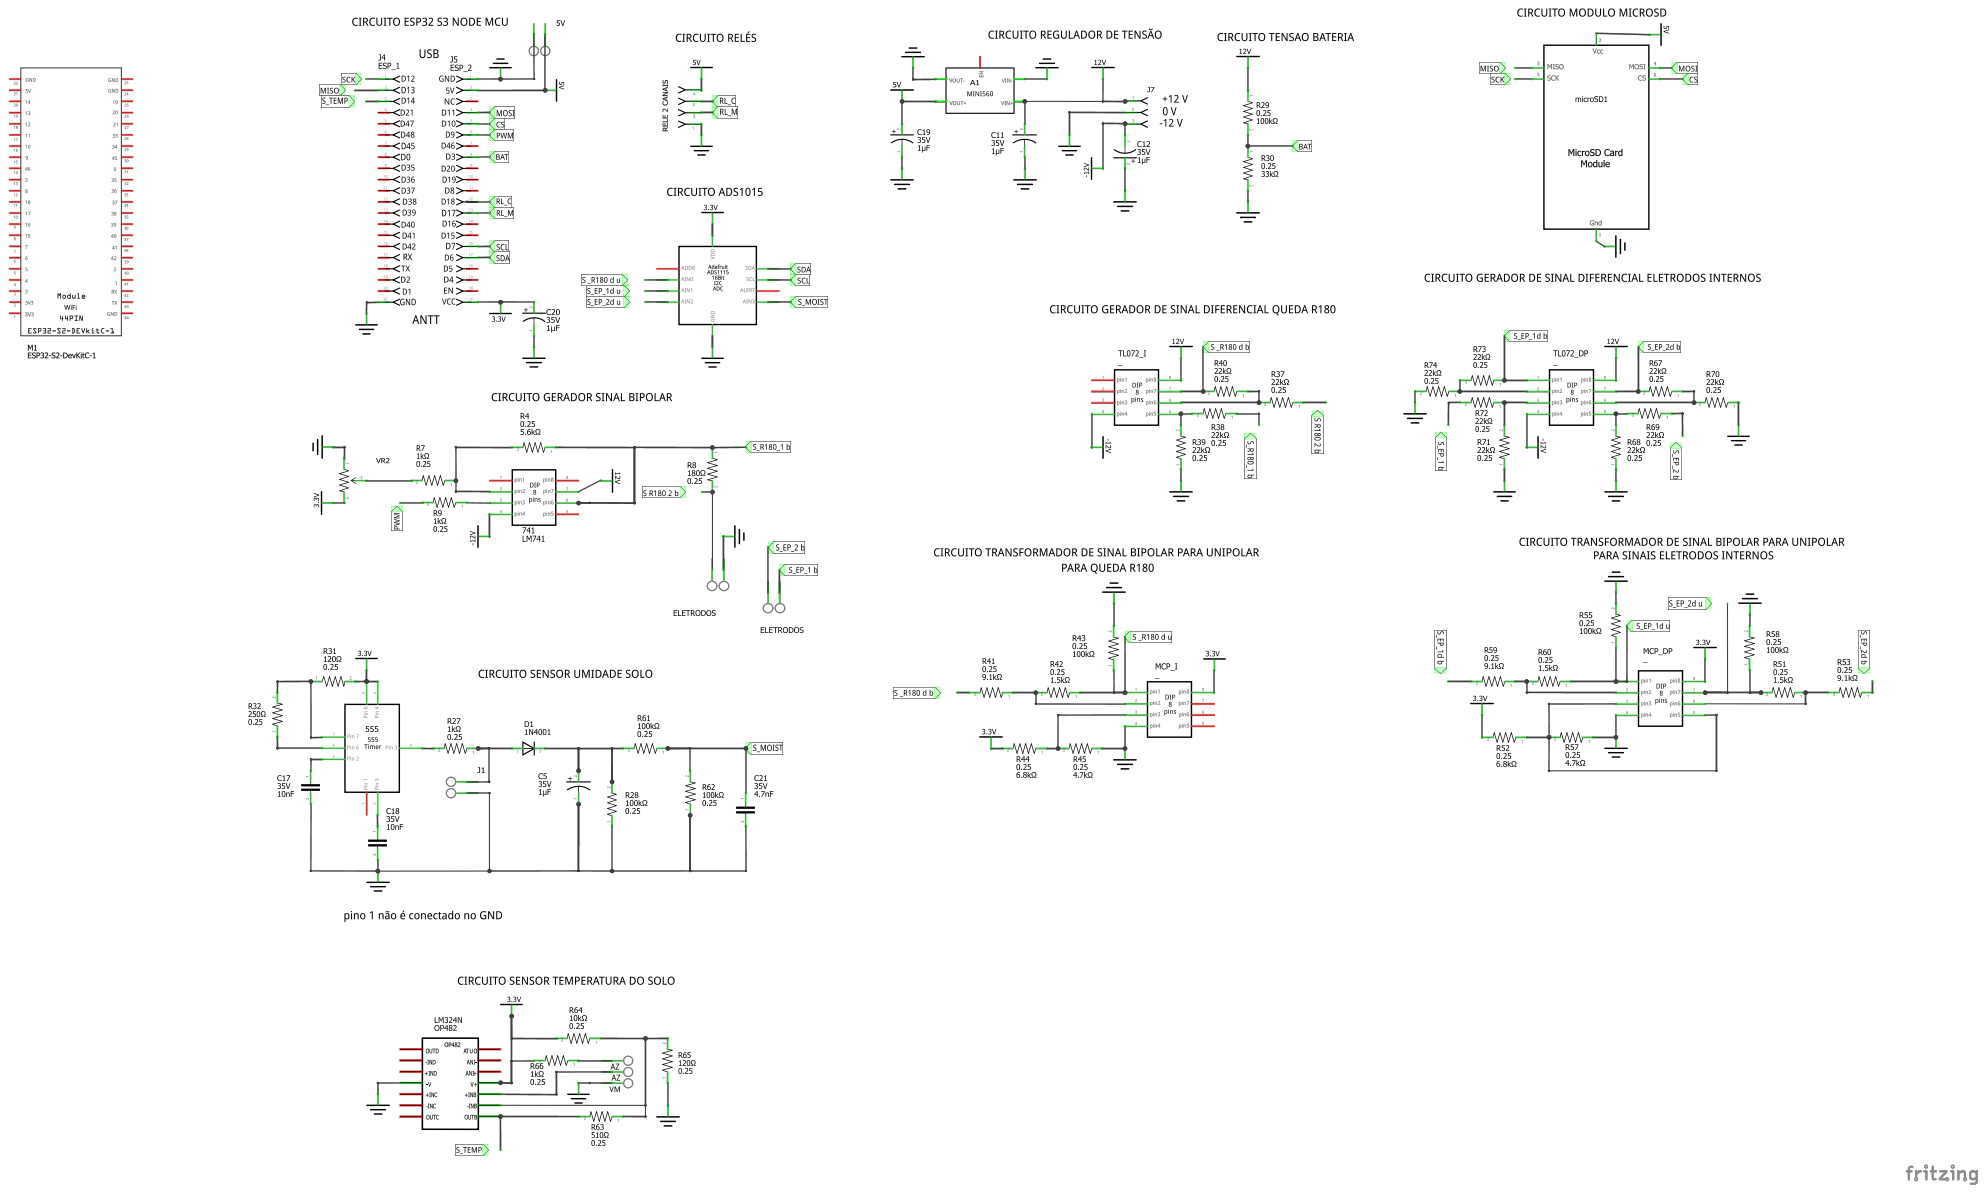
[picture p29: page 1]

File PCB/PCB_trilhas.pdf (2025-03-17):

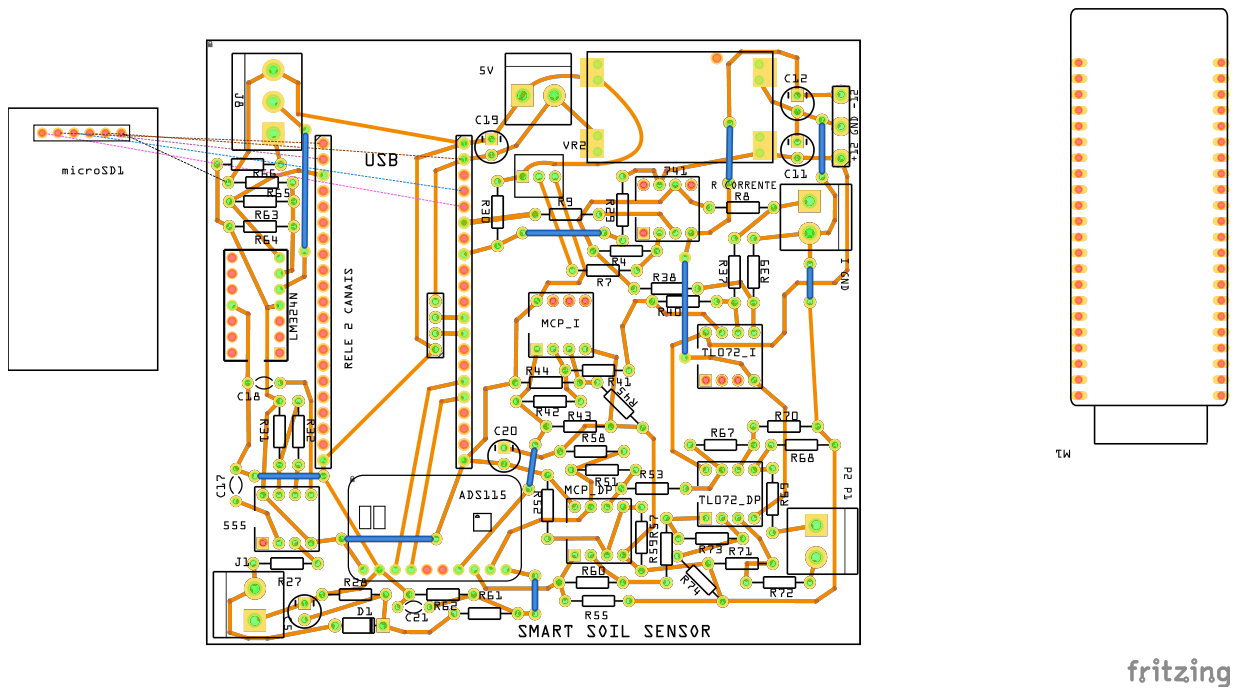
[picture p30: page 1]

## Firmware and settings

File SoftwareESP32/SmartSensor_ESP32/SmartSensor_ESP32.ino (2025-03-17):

/*
* Codigo para ESP32 S3 
  Firmware 3.0.5
 *  Na primeira vez que for usar esse programa no seu computador, coloque  os diretorios SparkFun_ADS1015_Arduino_Library e NimbleBLE-Arduino 
 *  no diretorio de bibliotecas do Arduino ID (Documentos/Arduino/Libraries). 
 *  O procedimento é copiar e colocar os diretorios.
 */

/*
  PWM gerado pela ESP32
  ADS 1015 com biblioteca . Ganho 1 . Alimentacao em 3.3 V . 3300 SPS. Biblioteca SparkFun_ADS1015_Arduino_Library
  Leitura de sinal unipolar de corrente, dp eletrodo 1 dp eletrodo 2 --> calculo de DP entre Eletrodo 1 e 2 via codigo
  1 LM741 gera sinal bipolar simetrico
  2 TL072 gera sinal diferencial de corrente e inviduais dos eletrodo
  1,5 MCP6002 transforma sinal bipolar em unipolar (I,EP1 e Ep2). Unico par de resistor R3 e R4 para os dois sinais -- 
  Sinal Corrente e Eletrodo 2 e 3 no Canal 0 , 1  e 2 no ADS1015
  ESP32 lê sinal e converte usando equação obtida experimentalmente (fatores obtidos no Excel)
  Sensor de Umidade de Solo com 555 (sem ligar Pino 1 no GND com capacitor 1 uF) ==Canal 3 ADS1015
  Sensor PT100 em pino analogico da ESP32 (D14)
  Divisor de tensão para ler tensão de bateria (D3)
  Bluetooth BLE Bliblioteca NimBLE -> NIMBLE
  Recebe comando para medir CEa e Umida no formato C10@1 , em que 10 é frequencia e 1 é ID
  Envia dados da bateria no formato BXX , onde XX é a tensão, a cada 10s
  Envia dados de CEa e Umidade formato C10,20
  Envia dados de Temperatura  no formato T10 , a cada 10 s
  Analise de sinal para detecção de contato eletrodos - 0 A 100 %
  Aplica filtro de outlier nos dados dos canais remove maiores de 1.5 *mediana
  Calcula valor medio do absoluto do sinal para calcular CEA
  Salva sinais e analise em cartao de memoria SD

  Reinicia a cada 50 leituras
  Filtro da mediana nos sinais
*/

//Sensor
String name = "SSS";
float RES_I = 180.0;
float COR_A[] = { -6.269, -6.0382, -6.0917 };
float COR_B[] = { 9.941, 9.538, 9.61 };
float COEF_UM[2] = { -26.51895, 3.93791 };
float factor_umi = 1.0;
float COEF_TMPT[2] = { 176.366, -260.29578 };


//filtragem do sinal DP com base na mediana H e L
#include <algorithm>
#include <vector>

// watchdog
#include "esp_task_wdt.h"

//salvar sinal para analise
#include "FS.h"
#include "SD.h"
#include "SPI.h"
char *file_sinal = "/signal.txt";     //sinal
char *file_analise = "/analise.txt";  //analise do sinal
String dataS;                         //para linha para arquivo
String id = "";                       //id do ponto enviado pelo App
uint8_t id_test = 0;                  //id para modo continuo
bool save_sd = false;                 //alerta de funcionamento do cartao
//Bluetooth
#include "NimBLEDevice.h"
NimBLECharacteristic *pCharacteristic;
bool deviceConnected = false;
#define SERVICE_UUID "6E400001-B5A3-F393-E0A9-E50E24DCCA9E"         // UART service UUID
#define CHARACTERISTIC_UUID "6E400002-B5A3-F393-E0A9-E50E24DCCA9E"  //Precisa ser compativel com o App
String msg = "";                                                    //mensagem que será recebida e processada

//PWM para gerar sinal a ser emitido no solo
#define PIN_PWM 9  //
uint8_t chn = 0;   //canal 0
uint8_t res = 14;  //resolucao 14 bit ===0 a 2^14= 16384 //ESP32 S3 não funciona com 15 ou 16 bit. Para pequenas frequencias a resolução precisa ser grande

//ADS1015 para ler sinais com precisao
#include <SparkFun_ADS1015_Arduino_Library.h>
#include <Wire.h>
ADS1015 ads;  //ADS1015
#define I2C_SDA 6
#define I2C_SCL 7


//parametro para aquisição de dados
float freq_signal = 0;       //frequencia do sinal emitido no solo --> do App
float dt_sampling = 0.0;     //taxa de amostragem
uint8_t time_acq_rate = 10;  //10x a frequencia do sinal
#define N_ACQ 40             //40 AQUISICOES   (4 ondas completas)
unsigned long t_accq = 0;    //para fazer tempo de aquisição sem delay
bool acquisition = false;    //está adquirindo CEa e Umi?

//calculos de CEA : Canal 0 , 1  e 2 do ADS
float signal_cea[N_ACQ][4];  //row , column (4) - corrente,pot E2,potE1 , pot dif
float cea = 0.0;             //guardar CEa
char soil_contact = 'N';     //contato com solo

//Mede tensao da bateria
#define PIN_BAT 3             //
float vb = 0.0;               //tensao bateria
unsigned long last_time = 0;  //para fazer leitura enquanto naão mede CEa

//Umidade do solo
//Canal 3 do ADS1015
float v_umi = 0.0;          //tensao umidade
float umi = 0.0;            //umidade
unsigned long last_t_wait;  //para medir tempo de leitura

//leds
#define led1 39
bool state = LOW;

// Pt100  pino analogico da ESP32 S3
#define pin_temp 19  //
float temp = 0.0;    //temperatura do solo

//Modulo Rele CEa e Umi
#define pin_r_cea 18
#define pin_r_umi 17

//Tempo de processo para forçar um RESET
unsigned long time_start;
uint8_t contador = 0;  //contador de medições


//declara funcoes
void ProcessMsg(String msg);
void runAcqCea();
void CalcCEA();
float GetTemp();
float voltage_bat();
void appendFile(fs::FS &fs, const char *path, const char *message);
float calculateMedian(std::vector<float> &data);

//Conectado/Desconectado
class MyServerCallbacks : public NimBLEServerCallbacks {
  void onConnect(NimBLEServer *pServer) {
    deviceConnected = true;
  };
  void onDisconnect(NimBLEServer *pServer) {
    deviceConnected = false;
  }
};

//Receive Information
class MyCallbacks : public BLECharacteristicCallbacks {
  void onWrite(NimBLECharacteristic *pCharacteristic) {
    std::string rxValue = pCharacteristic->getValue();
    ProcessMsg(rxValue.c_str());
  }
};

//SETUP//
void setup() {

  //Define frequencia do CPU em 240 MHz
  setCpuFrequencyMhz(240);

  //start serial
  Serial.begin(115200);
  delay(1000);

  //Iniciar cartao sd
  if (!SD.begin(SS)) {
    Serial.println(F("Cartao Nao Iniciado"));
    save_sd = false;
  } else save_sd = true;

  //Modulo Rele
  pinMode(pin_r_cea, OUTPUT);     //rele como saida
  digitalWrite(pin_r_cea, HIGH);  //desliga rele
  pinMode(pin_r_umi, OUTPUT);     //rele como saida
  digitalWrite(pin_r_umi, HIGH);  //desliga rele

  //Pinos de entrada analogica
  pinMode(PIN_BAT, INPUT);
  pinMode(pin_temp, INPUT);

  //LED
  pinMode(led1, OUTPUT);
  digitalWrite(led1, LOW);

  //configura pin pwm
  pinMode(PIN_PWM, OUTPUT);
  digitalWrite(PIN_PWM, LOW);


  //ADS1115
  Wire.begin(I2C_SDA, I2C_SCL, 1000000);  //é necessário iniciar o Wire , ESP32 S3 qualquer pino pode ser usado 1 mhz
  //Wire.setClock(3400000);
  while (!ads.begin(0x48)) {
    Serial.println(F("Falha iniciar ADS."));
    delay(1000);
  }
  //Ajusta ganho e frequência de aquisição
  ads.setGain(ADS1015_CONFIG_PGA_1);              //gain:1, input range: ± 4.096V
  ads.setSampleRate(ADS1015_CONFIG_RATE_3300HZ);  //- 0X00C0 : 3300Hz
  ads.setMode(ADS1015_CONFIG_MODE_SINGLE);        //não pode ser continuou mode
  ads.useConversionReady(false);

  // BLE
  NimBLEDevice::init("SSS");


  NimBLEServer *pServer = NimBLEDevice::createServer();            // Configura o dispositivo como Servidor BLE
  pServer->setCallbacks(new MyServerCallbacks());                  //Configura para receber calls
  NimBLEService *pService = pServer->createService(SERVICE_UUID);  // Cria o servico UART
  pCharacteristic = pService->createCharacteristic(
    CHARACTERISTIC_UUID,
    NIMBLE_PROPERTY::READ | NIMBLE_PROPERTY::WRITE | NIMBLE_PROPERTY::NOTIFY);
  pCharacteristic->setCallbacks(new MyCallbacks());
  pService->start();  // Inicia o serviço
  pServer->getAdvertising()->start();

  //Cria cabeçalho do arquivo , se o arquivo nao existe no SD
  if (not SD.exists(file_sinal)) {
    appendFile(SD, file_sinal, "id;rep,freq,vi,ep1,ep2,dp,\r\n");
  }

  //Cria cabeçalho do arquivo , se o arquivo nao existe no SD
  if (not SD.exists(file_analise)) {
    appendFile(SD, file_analise, "id;rep,freq,i_nh,nl,rnlh,vh,vl,rvlm,mean,ep1_nh,nl,rnlh,vh,vl,rvlm,mean,ep2_nh,nl,rnlh,vh,vl,rvlm,mean,dp_nh,nl,rnlh,vh,vl,rvlm,mean,cea,contact\r\n");
  }

  //Habilita o watchdog configurando o timeout para 10 segundos :: permite reiniciar a ESP32 automaticamente em caso de congelamento
  esp_task_wdt_config_t config = {
    .timeout_ms = 10 * 1000,  //  10 seconds
    .trigger_panic = true,    // Trigger panic if watchdog timer is not reset
  };
  esp_task_wdt_reconfigure(&config);
  esp_task_wdt_add(NULL);


  //Bate Rele para Indicar bom Funcionammento
  bool state = HIGH;
  for (uint8_t i = 0; i < 2; i++) {
    state = !state;
    digitalWrite(pin_r_cea, state);  //desliga rele
    delay(1000);
    digitalWrite(pin_r_umi, state);  //desliga rele
    delay(1000);
  }

}  //fim do void SETUP()


//Loop Tradicional
void loop() {

  //Se está conectado  : mede tensao de bateria (esperando mensagem em segundo plano
  if (deviceConnected) {

    //se tiver estouro de tempo (s)
    if (millis() - last_time > 5000) {

      //pisca led
      last_time = millis();
      state = !state;
      digitalWrite(led1, state);

      //obtem dados de bateria e temperatura -- se não estiver adquirindo
      if (!acquisition) {

        //Tensao Bateria
        vb = voltage_bat();  //
        //Envia resposta para o aplicativo
        msg = "B" + String(vb, 1);
        pCharacteristic->setValue(msg);
        pCharacteristic->notify();  // Envia o valor para o aplicativo!
        //Aguarda
        delay(100);

        //Temperatura
        temp = GetTemp();
        //Serial.print(F("Temperatura(ºC) : ")); Serial.println(temp, 3);
        //Envia resposta para o aplicativo
        msg = "T" + String(temp, 1);
        pCharacteristic->setValue(msg);
        pCharacteristic->notify();  // Envia o valor para o aplicativo!
        //Aguarda
        delay(100);

        //status do SD
        if (!save_sd) msg = "SD FAIL";
        else msg = "SD OK";
        pCharacteristic->setValue(msg);
        pCharacteristic->notify();  // Envia o valor para o aplicativo!

        //nome do dispostivo
        msg = "NM" + name;
        pCharacteristic->setValue(msg);
        pCharacteristic->notify();  // Envia o valor para o aplicativo!
      }

      //Induz CEa continuo (freq 10Hz)
      //String command = "C10@" + String(id_test);
      //ProcessMsg(command);
      //id_test = id_test + 1;
    }
  }

  // Reseta o temporizador do watchdog (evita congelamento)
  esp_task_wdt_reset();
}

//Funcao Executada Quando Mensagem é Recebina pelo BLE
void ProcessMsg(String msg) {

  //Se Recebe comando para medir
  if (msg.indexOf("C") > -1) {  //se tem a palavra C   C10@1   10 é frequencia   1 é ID
    contador = contador + 1;
    //Serial.print(contador);
    //Serial.print(",");
    time_start = millis();
    //Define acquisition para não ler Temperatura e Bateria
    acquisition = true;                 //seta como inicio de aquisicao --> nao mede temp e vb
    msg.remove(0, 1);                   //remove o primeiro caracteres C
    uint8_t idf = msg.indexOf("@", 0);  //acha o separadores
    String a = msg.substring(0, idf);   //extrai variavel entre separador
    freq_signal = a.toFloat();          //converte string na frequencia em float
    msg.remove(0, idf + 1);             //remove a frequencia e @
    id = msg;                           //id é o resto de msg --> usado para salvar sinal
    //Serial.print(id);
    //Liga Rele CEA para emitir sinal no solo
    digitalWrite(pin_r_umi, HIGH);  //desliga  rele umidade
    digitalWrite(pin_r_cea, LOW);   //liga rele cea
                                    //

    //inicia PWM
    ledcAttach(PIN_PWM, freq_signal, res);
    ledcWrite(PIN_PWM, 8192);  //pwm 50% duty cicle

    //Configura intervalo de leitura -- máxima frequencia de leitura é 680 Hz
    if (freq_signal <= 62) time_acq_rate = 10;                          //menor que 62 8x freq
    else if (freq_signal > 62 && freq_signal <= 83) time_acq_rate = 6;  //entre 62 e 83 6x freq
    else time_acq_rate = 4;                                             //maior que 83
    dt_sampling = 1000.0 / (float(time_acq_rate) * freq_signal);        // milisegundos;
    delay(1000);                                                        //espera até estabilizar PWM

    //Chama funcao de aquisicao do sinal e salva no vetor float v[NACQ][4]
    runAcqCea();
    //Serial.print(F(", "));
    //Serial.print(millis() - time_start);

    //Função que calcula a CEA e simultaneamente analisa o sinal
    CalcCEA();
    //Serial.print(F(","));
    //Serial.print(millis() - time_start);

    //desliga PWM
    ledcWrite(PIN_PWM, 0);

    //Mede umidade
    digitalWrite(pin_r_umi, LOW);   //liga rele umidade
    digitalWrite(pin_r_cea, HIGH);  //desliga rele cea
    delay(1000);                    //espera solo carregar como capacitor

    //Incia aquisicicao
    v_umi = 0;  //zera valor
      //media de 10 valores a cada 10 ms
    for (uint8_t i = 0; i < 10; i++) {
      v_umi = v_umi + (ads.getSingleEndedMillivolts(3) / 1000.0);  //umidade no canal A3
      delay(10);
    }

    v_umi = v_umi / 10.0;
    //Serial.print(F("Tensao Umidade (V) : "));  Serial.println (v_umi, 2);
    //Equação Calibração
    umi = COEF_UM[0] * log(v_umi / factor_umi) + COEF_UM[1];
    if (umi < 0) umi = 0;
    //Serial.print(F("Umidade (%) : ")); Serial.println (umi, 1);

    //Serial.print(F(", "));
    //Serial.print(millis() - time_start);

    //Desliga Rele não emitir sinal no solo
    digitalWrite(pin_r_umi, HIGH);  //desliga rele
    digitalWrite(pin_r_cea, HIGH);  //desliga rele

    //Envia para aplicativo
    msg = "C" + String(cea, 1) + ", " + String(umi, 1) + ";" + String(v_umi, 2) + ", " + soil_contact;  //
    pCharacteristic->setValue(msg);
    pCharacteristic->notify();  // Envia o valor para o aplicativo!
    //Serial.print("MSG : "); Serial.println(msg);  Serial.println(".......");

    //Retorna a leitura de temperatura e tensao de bateria
    acquisition = false;

    //Depois de calcar CEA e enviar para aplicativo salva o dado no SD
    for (uint8_t i = 1; i < N_ACQ; i++) {  //ignora primeiro valor
      dataS = id + ", " + String(freq_signal) + ", ";
      for (uint8_t j = 0; j < 4; j++) {
        //Serial.print(signal_cea[i][j], 2);
        //Serial.print(F("\t"));
        dataS = dataS + String(signal_cea[i][j], 2) + ", ";
      }
      //Serial.println();
      dataS = dataS + "\n";
      appendFile(SD, file_sinal, dataS.c_str());
    }
    //Serial.print(F(","));
    //Serial.println(millis() - time_start);

    //Indica que ESP está ficando lenta ==> força reinicialização
    //if (millis() - time_start > 10000) ESP.restart();
    if (contador > 30) ESP.restart();
  }
}  //Fim da funcao ProcessaMsg
//Final do Arquivo

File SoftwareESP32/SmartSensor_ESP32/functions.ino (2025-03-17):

//Adquire sinal para calcular CEA
void runAcqCea() {
  uint8_t n_actual = 0;  ////acquisicao atual

  //enquanto nao atinge N_ACQ
  while (n_actual < N_ACQ) {

    //se teve estouro de tempo
    if (millis() - t_accq > dt_sampling) {

      //resete timer
      t_accq = millis();

      //para cada um dos tres canais
      for (uint8_t j = 0; j < 3; j++) {  //chanel 0 (current)  1 (E2) 2 (E3)
        signal_cea[n_actual][j] = COR_A[j] * (ads.getSingleEndedMillivolts(j) / 1000.0) + COR_B[j];
      }

      //Dados diferencial eletrodos calculado
      signal_cea[n_actual][3] = signal_cea[n_actual][1] - signal_cea[n_actual][2];

      //Proximo ponto
      n_actual++;
    }
  }
}


//Calcula CEA e simultaneamente analisa sinal

void CalcCEA() {

  soil_contact = 'S';                          //Inicialmente tem contato
  float mean_cea[4] = { 0.0, 0.0, 0.0, 0.0 };  //guarda media do absoluto dos 4 sinais
  //para gerar linha de anlise
  dataS = id + "," + String(freq_signal, 1) + ",";  //para arquivo

  //para cada sinal  I, EP1,EP2, DP
  for (uint8_t j = 0; j < 4; j++) {

    Serial.print(j);
    Serial.print("\t");
    uint8_t nl = 0, nh = 0;    //numero de pontos em H e L
    float vl = 0.0, vh = 0.0;  //tensao média em H e L

    float rn_lh = 0.0;  //relacao numero pontos L e H
    float rv_lh = 0.0;  //relacao tensao em L e H

    //inicialmente,  separa o sinal em positivo e negativo para calcular a mediana
    std::vector<float> signal_h;
    std::vector<float> signal_l;

    for (uint8_t k = 0; k < N_ACQ; k++) {
      if (signal_cea[k][j] > 0) {
        signal_h.push_back(signal_cea[k][j]);
      } else {
        signal_l.push_back(signal_cea[k][j]);
      }
    }
    //calcula mediana em L e H
    float vh_median = calculateMedian(signal_h);
    float vl_median = calculateMedian(signal_l);
    Serial.print("Mediana :");
    Serial.print(vh_median);
    Serial.print("\t");
    Serial.print(vl_median);

    //varre sinal original e filtra se valor menor que 1.5 *mediana
    //calcula media do absoluto do sinal sem os outlier
    //calcula media e quantidade H e L sem os outiler
    for (uint8_t k = 0; k < N_ACQ; k++) {
      if (signal_cea[k][j] > 0 and signal_cea[k][j] < 1.25 * vh_median and signal_cea[k][j] > 0.75 * vh_median ) {          //se positivo e não diverger da mediana
        mean_cea[j] = mean_cea[j] + abs(signal_cea[k][j]);                        //para media
        nh = nh + 1;                                                              //conta NH
        vh = vh + signal_cea[k][j];                                               //soma para média VH
      } else if (signal_cea[k][j] <= 0 and signal_cea[k][j] > 1.25 * vl_median and signal_cea[k][j] < 0.75 * vl_median) {  //se negativo e não diverger da mediana
        mean_cea[j] = mean_cea[j] + abs(signal_cea[k][j]);                        //para media
        nl = nl + 1;                                                              //conta NL
        vl = vl + signal_cea[k][j];                                               //soma para média VH
      }
    }

    //calcula média dos sinais filtrados
    mean_cea[j] = mean_cea[j] / float(nh + nl);
    Serial.print(mean_cea[j]);
    Serial.print("\t");

    //relacao rnlh --numero de pontos
    if (nh > 0) rn_lh = float(nl) / float(nh);
    else rn_lh = 99.9;  //para evitar inf
    Serial.print(rn_lh, 2);
    Serial.print("\t");

    //media vh
    if (nh > 0) vh = vh / float(nh);
    else vh = 99.9;  //para evitar inf

    //media vl
    if (nl > 0) vl = vl / float(nl);
    else vl = -99.9;  //para evitar inf

    //relacao rnlh --numero de valores  de H e L
    rv_lh = vl / vh;
    Serial.print(rv_lh, 2);
    Serial.println("\t");

    //indicadores de mal contato
    if (rn_lh < 0.5 or rn_lh > 1.5) soil_contact = 'N';     //0.5 < RN < 1.5
    if (rv_lh < -2.0 or rv_lh > -0.10) soil_contact = 'N';  //-0.25 < RV < -1.75

    //MEAN EP1 ou MEAN EP2 < 8.0 (caso especifico para solo com baixa CEa sem contato no GND)
    if ((j == 1 or j == 2) and mean_cea[j] > 8.0) soil_contact = 'N';

    //gera linha para analise posterior
    dataS = dataS + String(nh) + "," + String(nl) + "," + String(rn_lh, 2) + ",";
    dataS = dataS + String(vh, 2) + "," + String(vl, 2) + "," + String(rv_lh, 2) + ",";
    dataS = dataS + String(mean_cea[j], 3) + ",";
  }
  //CEA= i(mA)/(2 * PI * a (m) * DP (V))
  cea = (1000.0 * mean_cea[0] / float(RES_I)) / (2.0 * 3.14159 * 0.3 * mean_cea[3]);
  //limitação do número de caracter enviado para o App
  if (cea > 100) cea = 99.9;

  //salva analise no arquivo
  dataS = dataS + String(cea, 1) + "," + soil_contact + "\n";
  Serial.print(dataS);
  appendFile(SD, file_analise, dataS.c_str());
}

// Function to calculate the median of an array, ignoring zero values
// Function to calculate the median of a vector
float calculateMedian(std::vector<float> &data) {
  // Ensure the vector is not empty
  if (data.empty()) {
    return 0.0;  // Return 0 for an empty vector (you can choose a different value)
  }

  // Sort the vector in ascending order
  std::sort(data.begin(), data.end());

  // Calculate the median
  size_t size = data.size();
  if (size % 2 == 0) {
    // If the size is even, return the average of the middle two elements
    return (data[size / 2 - 1] + data[size / 2]) / 2.0;
  } else {
    // If the size is odd, return the middle element
    return data[size / 2];
  }
}

//mede e tensão de uma bateria responsavel pela fonte positiva -- > /Executado no Nucleo 1
float voltage_bat() {

  float value = 0;
  uint8_t R1 = 99;  //kohm
  uint8_t R2 = 33;  //kohm

  //usa media de 10 valores
  for (int i = 0; i < 10; i++) {
    value = value + 3.3 * analogRead(PIN_BAT) / 4096.0;
    delay(10);
  }
  value = value / 10.0;
  return (value * float(R1 + R2)) / (float(R2)) / 3.0;  //calcula tensão na entrada no divisor de tensão e divide por 3 ==> tensão de uma bateria
}

//obtem tensao gerada pelo PT100
float GetTemp() {

  float temp = 0;
  int n = 20;

  //media de 20 valores a cada 10 ms
  for (int i = 0; i < n; i++) {
    temp = temp + 3.3 * analogRead(pin_temp) / 4096.0;
    delay(10);
  }
  temp = temp / float(n);

  //Serial.print(F("Voltage Temp: ")); Serial.println(temp, 3);
  return COEF_TMPT[0] * temp + COEF_TMPT[1];
}

//Salva sinal
void appendFile(fs::FS &fs, const char *path, const char *message) {
  File file = fs.open(path, FILE_APPEND);
  if (!file) {
    save_sd = false;
    return;  //se não abri arquivo , retorna
  } else save_sd = true;
  file.print(message);
  file.close();
}

//Final do Arquivo

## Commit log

2025-03-17 Versão Inicial
    [ListaMateriais_Estrutura.csv, ListaMateriais_PCB.csv, PCB.fzz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]
2025-03-24 Inclusão Datasetes
    [Dataset_CEA_RP_RROD_SOLO_CS_RS.xlxs.xlsx, Dataset_CEA_RROD_SOLO_SR_GO.xlxs.xlsx, Dataset_CEA_SOLO_SL_MG.xlsx]
2025-04-02 DataSet Alegre/ES
    [Dataset_CEA_SOLO_AL_ES.xlsx]
2025-04-02 Adicionado banco de dados
    [Dataset_CEA_CB_MG.xlsx]
2025-04-07 Novo dataset
    [Dataset_CEA_SOLO_RF_PE.xlsx]
